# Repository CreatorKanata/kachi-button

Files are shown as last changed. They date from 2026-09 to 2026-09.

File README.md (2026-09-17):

<p align="center">
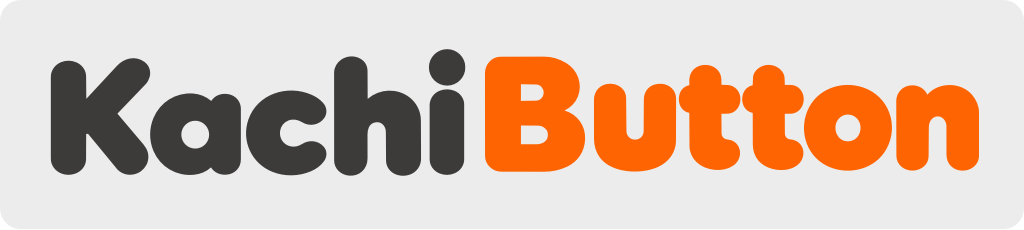
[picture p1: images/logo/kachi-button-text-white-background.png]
Kachi Button
  
</p>

<p align="center"><strong>Click for Fun. Type for Real.</strong></p>

Kachi Button is an open-source, programmable keychain keyboard. Enjoy the click of its mechanical keys, then connect it via USB-C to type your favorite phrases with a single press. “Kachi” is the Japanese sound of a click.

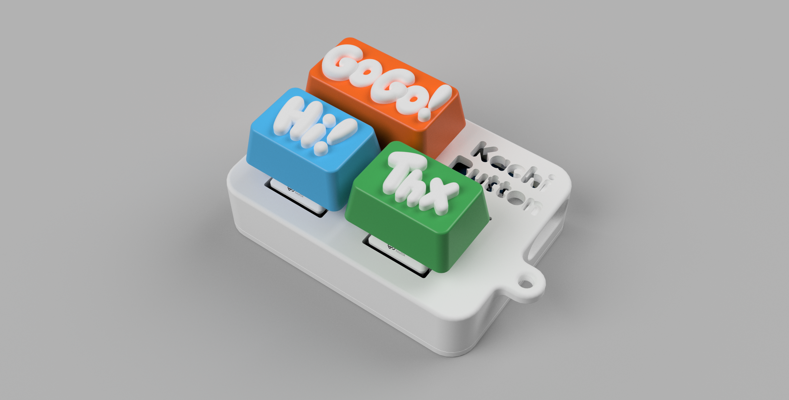
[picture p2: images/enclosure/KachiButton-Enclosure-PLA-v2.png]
Kachi Button with the PLA v2 enclosure


The product concept combines three mechanical keys, a USB-C connection, and a compact enclosure. Use cases include quick game chat messages and recurring prompts such as “OK,” “Continue,” and “Do it.” The image above is a 3D rendering of the PLA v2 enclosure and keycaps.

## Hardware v1

The first PCB uses a WCH CH552E, three MX-compatible switches, a USB-C connector, and a status LED. One large key sits above two smaller keys. The two-layer board has R5 corners and is intended for a snap-fit enclosure. All resistors and capacitors use 0402 packages.

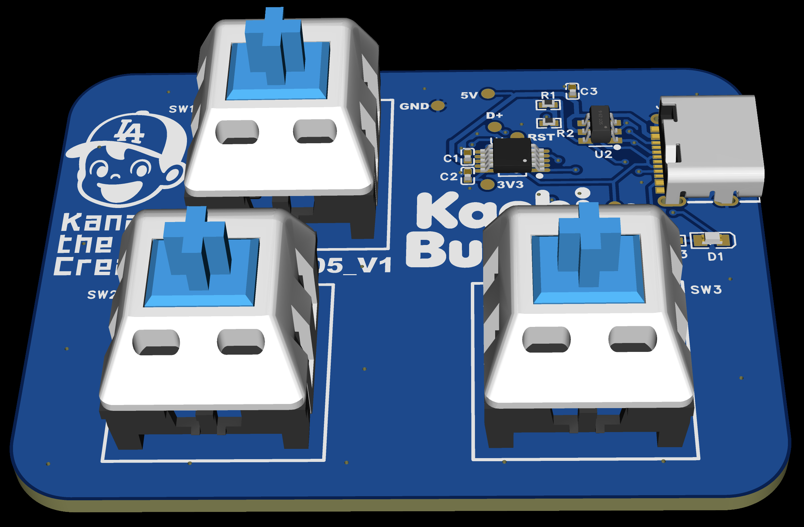
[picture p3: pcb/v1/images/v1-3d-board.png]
Kachi Button v1 PCB 3D rendering


See the [top and bottom board previews](pcb/v1/README.md#board-previews) for routing and silkscreen details.

Manufacturing exports are available in [pcb/v1](pcb/v1/README.md), including Gerber, BOM, pick-and-place, and STEP files. The design record explains the circuit, component choices, layout, and outstanding validation.

The [USB keyboard firmware](firmware/README.md) defaults to `Go Go!`, `Hi!`, and `Thx` on the upper, lower-left, and lower-right keys. A USB command-line tool can edit and save each key’s text, repeat count, and interval in milliseconds; host-initiated firmware upload is supported. See the [bring-up record](firmware/bring-up.md) for build and hardware verification. A browser-based configuration tool remains planned; enclosure fit and broader hardware validation remain separate checks.

## Development

See the [detailed specifications](docs/README.md) for product requirements, PCB dimensions and placement, firmware, and the enclosure to be designed in 3D CAD. The latest design decisions fix keycap sizes at 33 × 18 mm for the upper key and 25 × 18 mm for each lower key; enclosure dimensions remain provisional. The purchased USB-C cable is nominally 10 cm long.

For keyboard software, start with [firmware development](docs/firmware-development.md), the [feature inventory](docs/firmware-features.md), and [firmware internals](docs/firmware-internals.md). These describe the implemented CLI configuration and upload paths; the product specifications also include future requirements.

PCB and schematic work uses the EasyEDA MCP / `easyeda-api` skill workflow. See [PCB development with EasyEDA](docs/pcb-development.md) for connection setup, editing practices, verification, and export steps.

Chat with contributors in Japanese. Write documentation, code, code comments, issues, and pull requests in English, as specified in [AGENTS.md](AGENTS.md).

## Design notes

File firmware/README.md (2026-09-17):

# Kachi Button firmware

Configurable text macros for PCB v1 (CH552E), September 12, 2026.

See the [development guide](../docs/firmware-development.md), [feature inventory](../docs/firmware-features.md), and [internals](../docs/firmware-internals.md) for task-oriented documentation.

| ID | Physical key | GPIO | Default text |
| --- | --- | --- | --- |
| 0 | Top / SW1 | P1.5 | `Go Go!` |
| 1 | Lower left / SW2 | P1.6 | `Hi!` |
| 2 | Lower right / SW3 | P1.7 | `Thx` |

Each key has 0–32 printable ASCII characters, 1–99 repetitions and a
0–60,000 ms repeat interval. Defaults use one repetition and 0 ms.
An empty text disables that key. One physical press executes the entire macro;
holding the key does not retrigger it. No Enter or separator is added.

The interval is the software delay after the final release report of one copy
is queued and before the next copy begins. Each character still has a key-down
and release report, paced by the USB endpoint. Actual host-observed timing is
quantized by the 10 ms USB polling interval and host scheduling; this is not a
precision pulse generator. A zero interval adds no extra delay.

Use a US/ABC-compatible Latin keyboard layout with other modifiers released.
The firmware accounts for Caps Lock, but does not implement IME conversion,
Unicode text, arbitrary keyboard layouts, or automatic Enter.

Inputs have pull-ups and 15 ms debounce. Held startup/resume keys require release.
Only one macro runs at a time; presses while busy are discarded until release.
Simultaneous presses use Top, Left, Right priority. Settings updates do not alter
an already running macro; each accepted press snapshots its text/count/interval.
USB reset or suspend cancels the current macro and staged configuration edit.

## Configure from the host

Python 3 and a libusb shared library are required (on macOS, 1.0.30 or newer). The [server-free browser settings page](../configure-html/README.md) uses Chrome WebUSB instead
of these Python tools. No CDC serial port is included. These commands use vendor requests on the keyboard's
USB control endpoint without claiming/detaching its HID interface.

```sh
# Read all keys and save status.
python3 firmware/configure.py get

# A single top-key press types Go! three times with 250 ms gaps; persist it.
python3 firmware/configure.py set 0 --text 'Go!' --repeat 3 --interval-ms 250 --save

# Changes without --save apply in RAM; persist all three keys explicitly.
python3 firmware/configure.py save
```

For a library outside the search path, place
`--libusb /path/to/libusb-1.0.dylib` before the subcommand, or set the
`KACHI_LIBUSB` environment variable. macOS libusb 1.0.29 was observed deadlocking
in exit during USB detach; the tool rejects it before opening USB. Version
1.0.30 contains [Darwin concurrency fixes](https://github.com/libusb/libusb/blob/master/ChangeLog). Set operates on one key;
`--repeat` defaults to 1 and `--interval-ms` to 0. Run one configuration writer
at a time. The tool checks capability, validates input, applies a complete key
atomically, reads it back, and waits for verified save completion when requested.

## Saved settings

CH552 provides 128 logical DataFlash bytes. This version uses bytes 0–113:
`KC`, schema 1, three 36-byte macros, CRC-16/CCITT-FALSE (little endian), and
commit marker `0xa5`. Each macro is count, length, interval-ms low/high bytes,
then 32 zero-padded ASCII bytes. Addresses 114–127 remain unused.

Save invalidates the marker first, updates and reads back every changed byte,
then writes the commit marker last. Identical saves perform no EEPROM writes.
Invalid schema, checksum, text, ranges, or commit marker loads all defaults.
Only explicit save writes EEPROM. Flashing application code leaves it intact.

There is one record, not two: interrupted save can lose the previous saved
configuration and fall back to defaults. The implementation never intentionally
loads a partially committed record. Unchanged valid records remain available if
failure occurs before invalidation. A save error is returned to the host.

The pinned [CH55xduino EEPROM implementation](https://github.com/DeqingSun/ch55xduino/blob/ch55xduino/ch55xduino/ch55x/cores/ch55xduino/eeprom.c)
uses logical byte addresses 0–127 and the CH552 DataFlash write sequence.
The wrapper masks interrupts for each byte's protected register accesses; saving
runs in the foreground, with status requests available between byte operations.

## Firmware upload and waiting

From the repository root, use these short commands:

```sh
make flash-first  # First flash or recovery: already connected in native WCH ISP.
make flash        # Later updates: connected as a running Kachi Button.
```

Both commands flash the existing `firmware/build/compiled/kachi_button.ino.hex`
with verification enabled; neither rebuilds it. Build first if the HEX is absent
or you have changed firmware source. Override the image with
`make flash FIRMWARE=/absolute/path/to/file.hex` (also supported by `flash-first`).
A first-flash command does not put a running keyboard into ISP; use `make flash`
for that. If an update reports `found 0 / 1`, the device is already in ISP:
use `make flash-first`. Connect only the intended target.

For tools outside PATH, copy `firmware/local.mk.example` to `firmware/local.mk`
and set `PYTHON`, `WCHISP`, and optionally `LIBUSB` to their installed paths.
The local file is ignored by Git. Values are plain paths, without shell quotes;
spaces in paths are supported. macOS requires libusb 1.0.30+ matching Python's
architecture. `make` shows help; `make -n flash` previews the command without USB
access. Existing long-form commands remain available below.

Protocol v2 accepts a host ISP-entry command from normal mode or write-wait mode.
An AI/host tool can now update firmware without a physical key gesture:

```sh
python3 firmware/flash.py --status
python3 firmware/flash.py firmware/build/compiled/kachi_button.ino.hex --wchisp /path/to/wchisp

# Optional: enter native ISP without immediately flashing.
python3 firmware/flash.py --enter
```

The uploader validates the known firmware protocol, requests ISP, waits for the
new USB identity, and invokes wchisp with verification enabled. It refuses
unknown protocols, missing files/tools, multiple keyboard targets, or an already
attached WCH ISP target. Keep only the intended target attached during upload.
These local USB commands are intentionally host-controlled, not authenticated.

The physical alternative remains: hold all three keys before connecting USB,
then keep holding for 2 seconds. Slow blinking (250 ms on/off) changes to fast
blinking (75 ms on/off). After confirmation, release the keys and wait indefinitely.
USB reset/suspend and key changes do not clear confirmed waiting; power/MCU reset
does. Text output is suppressed in this state. Reconnect without keys for normal
operation. Entering active normal HID mode lights the LED for 2 seconds, then
leaves it off. Each debounced physical press then produces one 30 ms on pulse
and returns to off. The entry indication takes priority during its 2 seconds;
presses still type normally but do not interrupt or extend that indication.
Reconfiguration or resume starts a new entry indication.
This includes presses ignored during a running macro; holding a key does not
repeat the pulse. Software-generated repetitions do not trigger extra pulses.
The nonblocking pulse timer yields to startup/write-wait patterns and USB suspend.

The application retains identity `1209:c55d` while waiting. Native ISP starts
only when the host requests it, then the application LED loop stops. Native ISP
has its own timeout; use the integrated uploader when programming. A successful
flash resets the device into the new application. Fast blinking is guaranteed by
the application waiting logic, not during native ISP itself.

Bootloader entry follows pinned CH55xduino 0.0.26 `USBCDC.c`: USB detach, disable
interrupts/timer mode, 100 ms delay, call CH552 address `0x3800`. No configuration
registers or bootloader code are rewritten. Boards still running protocol-v1 firmware
require the three-key wait for the one-time upgrade; this uploader also
supports that legacy wait state. The oldest K/N/A firmware requires hardware ISP.

### Native ISP and recovery

A blank CH552 normally appears as WCH ISP `4348:55e0`. Use tested
[wchisp](https://github.com/ch32-rs/wchisp) 0.3.0, commit
`cefd8707df345f1fbd7795e15367281f440bbf05`:

```sh
wchisp info --chip CH552
wchisp flash firmware/build/compiled/kachi_button.ino.hex
```

The command erases application flash, programs, verifies, and resets. If an
upload fails after erasing the application, use native ISP directly for recovery.
The retained factory hardware-entry setting uses D+. With USB disconnected,
connect D+ to 5 V through a 10 kOhm resistor, then reconnect USB; remove the
pull-up after ISP entry. Never directly short D+ to 5 V. PCB v1 has labeled test
pads. This hardware recovery wiring has not been physically tested on this board.
See [upstream entry instructions](https://github.com/DeqingSun/ch55xduino#installation).

## Build and test

Dependencies: Python 3, a native C compiler, Arduino CLI and CH55xduino 0.0.26
(SDCC build.13407_4, MCS51Tools 2026.07.10); tested CLI version is 1.3.1.

```sh
export ARDUINO_DIRECTORIES_DATA="$PWD/.arduino-data"
arduino-cli core update-index --additional-urls https://raw.githubusercontent.com/DeqingSun/ch55xduino/ch55xduino/package_ch55xduino_mcs51_index.json
arduino-cli core install CH55xDuino:mcs51@0.0.26 --additional-urls https://raw.githubusercontent.com/DeqingSun/ch55xduino/ch55xduino/package_ch55xduino_mcs51_index.json
python3 firmware/build.py --data "$ARDUINO_DIRECTORIES_DATA"
```

Use `--cli /path/to/arduino-cli`, `--out /path/to/build`, or `--test-only` as
needed. All limits, timing and identifiers are centralized in `config.py`.
Output is `firmware/build/compiled/kachi_button.ino.hex` with map/memory files.

Build staging copies pinned upstream HID descriptors/control handlers and makes
checked substitutions for product strings, power, lifecycle hooks and vendor
requests. Application flash is limited to 14,336 bytes; 148 XRAM bytes are
reserved for USB, leaving 876 for the application. CH55xduino's USB code and the
ASCII map are LGPL-2.1; retain the corresponding source, license and relinkable
objects when redistributing binaries.

USB identity is the upstream development VID:PID `1209:c55d`, not an allocated
production identifier. One boot keyboard interface uses endpoint `0x81` with
eight-byte reports at 10 ms. Remote wake is not advertised. Suspend extinguishes
the normal LED; confirmed write-wait continues blinking. Power consumption and
suspend compliance have not been measured.

## USB control protocol v2

All requests use wValue `0x4b42`. IN type is `0xc0`; OUT type is `0x40`.
OUT commands have zero data length; mutation occurs only after status-stage ACK.
A new SETUP cancels an unacknowledged command. Invalid requests stall.

| Request | Direction/length | wIndex | Meaning |
| --- | --- | --- | --- |
| `0x5a` | IN / 4 | 0 | `KB`, version 2, waiting flag |
| `0x5b` | OUT / 0 | 0 | Enter native ISP from either mode |
| `0x60` | IN / 8 | 0 | `KC`, version 2, max text, max count, result, saving, dirty |
| `0x61` | IN / 1–8 | offset high, key ID low | Read a macro slice, within 36 bytes |
| `0x62` | OUT / 0 | key ID | Begin a new single-key staged edit |
| `0x63` | OUT / 0 | byte value high, offset low | Append next sequential byte, 0–35 |
| `0x64` | OUT / 0 | 0 | Validate and atomically apply the complete staged macro |
| `0x65` | OUT / 0 | 0 | Queue save, poll info for completion |
| `0x66` | IN / 8 | 0 | Factory ID: `KI`, format 1, five ID bytes, most significant first |

Save result: 0 success, 1 pending, 2 storage error. Edits and ISP entry stall
while saving; read-only requests remain available. Repeating an edit must start
with begin; a second client can replace a staged edit, so writers must serialize.
No configuration command emits keyboard input.

## Validation

Eight native C suites cover scanning, default reports, repetitions and ms gaps,
snapshot behavior, startup waiting, remote ISP validation, the actual EP0 adapter,
settings bounds, EEPROM round-trip, corruption and all injected partial writes.
Six Python tests cover uploader gating/ordering and configuration encoding/wire
commands. Native tests do not prove physical timing, EEPROM or signal quality.
See [bring-up.md](bring-up.md) for build sizes and actual hardware checks.

Dismiss macOS Keyboard Setup Assistant with Quit; three keys cannot complete its
full-keyboard identification procedure.

## Save-completion LED

Firmware with the September 13, 2026 save-feedback change lights the LED for
1 second after a successful, verified settings save in normal HID mode. This
also applies to an unchanged save and saves from the Python tool. Temporary
apply and failed saves do not trigger it. This device-side change requires a
firmware update; changing the HTML alone cannot enable it on older firmware.

Save feedback takes priority over HID-entry and key-press indications; typing
continues and presses do not extend the 1-second duration. Another successful
save restarts it. Startup/write-wait blinking, USB suspend/reset, and ISP entry
retain priority and can cancel the indication. Native tests verify timer bounds,
wrap, failure, retrigger, and priority; physical LED timing is not measured.

The optional `0x66` request reads the factory 40-bit CH552 ID without ISP entry
or flash writes. It is available in normal and write-wait modes and during save.
Older protocol-v2 firmware stalls it; callers may show ID unavailable while
continuing settings operations. The USB serial-number descriptor remains absent.
See the [browser ID guide](../configure-html/README.md#factory-chip-id) for memory
addresses and the datasheet reference.

## USB manufacturer

New firmware advertises `HAPT Lab, LLC` as its USB manufacturer. The product
remains `Kachi Button`. Host tools and the browser accept both this name and
legacy `CreatorKanata` devices so existing firmware can still be upgraded.
Product/VID/PID and protocol checks remain in place; other manufacturers are
not accepted. Historical bring-up records retain the names observed at the time.

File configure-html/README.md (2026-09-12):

# Browser keyboard settings

A static HTML/CSS/JavaScript settings page for Kachi Button protocol v2.
No server, Python process, libusb installation, npm packages, or network requests
are needed to use the page. Open `index.html` in desktop Chrome, keeping the
adjacent JavaScript and CSS files in the same folder.
The project-root `configure-html/` directory can be copied on its own for use;
only regenerating protocol constants requires the sibling `firmware/` sources.

## Use

1. Connect the intended Kachi Button with USB.
2. Open `index.html` in Chrome and click **Connect USB**.
3. Select Kachi Button in Chrome's USB permission picker.
4. Edit Go Go! (top, ID 0), Hi! (lower left, ID 1), and Thx (lower right, ID 2).
5. Choose **Apply & save to device** for persistent settings, or **Apply temporarily**
   for RAM-only changes. Success is shown only after device read-back verification.
6. Click **Try your buttons**, select a US/ABC input source, and press a physical key.

Key names match the printed keycaps and remain fixed when the assigned text changes.
Each key heading uses three lines: small switch position, keycap name, then small ID.
This order is retained on narrow screens.

Text supports 0–32 printable ASCII characters; empty text disables a key.
Repetitions are 1–99, and the gap between full copies is 0–60,000 ms.
No Enter or separator is added. A count of 1 sends the text once. The interval
is not a per-character delay or a guaranteed start-to-start period.

The form does not write on each keystroke. Re-reading asks before discarding
unsubmitted edits. Disconnects and errors keep form values but require a fresh
connection before further writes. A failed multi-key operation may have applied
earlier keys; read the device before retrying. Updates are atomic per key, not
across all three keys. Save persists all keys, with the firmware's existing
single-record power-loss limitations. Run only one settings writer at a time,
including other browser tabs and Python tools.

## Browser transport

The page uses `navigator.usb.requestDevice`, checks the USB identity and protocol,
and sends vendor, device-recipient control transfers on endpoint zero. It does
not claim the HID interface, reset the device, use WebHID keyboard reports, or
change firmware. Chrome requires user permission for USB selection. Browser/OS
USB access restrictions still apply; this page does not disable them.

The [WebUSB control-transfer specification](https://wicg.github.io/webusb/#usbcontroltransferparameters)
distinguishes vendor device requests from protected HID interface requests.
See also [Chrome's WebUSB documentation](https://developer.chrome.com/docs/capabilities/usb).
File-origin USB availability depends on the browser's policy. If WebUSB is absent
or permission is denied, the page shows an error; it does not start a server or
silently substitute a native bridge. Safari/Firefox support is not assumed.

## Development and validation

Protocol constants are generated from `firmware/config.py`:

```sh
python3 configure-html/generate_config.py
node --test configure-html/tests/protocol.test.cjs
```

Seven Node tests cover encoding and bounds, device identity/read protocol, exact
staged commands, temporary changes, skipped unchanged keys, stalls, bad responses,
and save failures. Node is only required for these development tests.

On September 12, 2026, these tests passed. Chrome rendered the earlier local-bridge
prototype, but the browser automation policy rejected its connect-button action.
The final server-free page's Chrome USB read/edit/save checks remain pending;
simulator tests do not demonstrate actual browser/device compatibility. No device
settings were changed by the browser test and no firmware was flashed.

## Save-completion LED

Firmware with the September 13, 2026 save-feedback change lights the LED for
1 second after a successful, verified settings save in normal HID mode. This
also applies to an unchanged save and saves from the Python tool. Temporary
apply and failed saves do not trigger it. This device-side change requires a
firmware update; changing the HTML alone cannot enable it on older firmware.

Save feedback takes priority over HID-entry and key-press indications; typing
continues and presses do not extend the 1-second duration. Another successful
save restarts it. Startup/write-wait blinking, USB suspend/reset, and ISP entry
retain priority and can cancel the indication. Native tests verify timer bounds,
wrap, failure, retrigger, and priority; physical LED timing is not measured.

## Factory chip ID

Connect USB and Read device show **Chip ID**, the CH552 factory 40-bit ID,
formatted as five uppercase hexadecimal bytes, most significant first. It is
fixed by the chip and independent of key names, assigned text, and saved settings.
The browser reads it directly with a read-only USB request; it does not enter ISP.
Older firmware returns an unsupported-request stall and shows an update notice,
while the existing settings controls remain available. Transport errors and
malformed replies are not treated as a valid ID; disconnect clears the display.

The implementation follows the [WCH CH552 datasheet, section 6.7](https://cdn-learn.adafruit.com/assets/assets/000/129/847/original/CH552DS1.PDF?1715004485=).
It reads code addresses 0x3FFA, 0x3FFF, 0x3FFE, 0x3FFD, 0x3FFC, skipping the
reserved 0x3FFB. This is different from the shared chip-model register 0x52 or
USB VID/PID. Some ISP tools show only the lower four bytes in another order.
Eight browser protocol tests now include ID formatting, legacy stalls, malformed
responses, and disconnection. Native EP0 tests verify the byte order and request
validation while saving is active.

The September 13 JST firmware was flashed and verified. Host USB reads returned
`79-BE-CA-A2-BE` twice on the connected board and confirmed saved settings were
retained. The browser uses the same request; actual browser display is unverified.

## USB manufacturer

New firmware advertises `HAPT Lab, LLC` as its USB manufacturer. The product
remains `Kachi Button`. Host tools and the browser accept both this name and
legacy `CreatorKanata` devices so existing firmware can still be upgraded.
Product/VID/PID and protocol checks remain in place; other manufacturers are
not accepted. Historical bring-up records retain the names observed at the time.

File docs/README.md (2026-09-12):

# Kachi Button Development and Specifications

Updated September 12, 2026. These English specifications consolidate the preliminary concepts, the design discussion, PCB v1 exports, and the latest product reference.

| Document | Scope |
| --- | --- |
| [Product](spec/product-spec.md) | Purpose, experience, scope, purchased cable, and delivery milestones |
| [PCB](spec/pcb-spec.md) | Electrical interfaces, dimensions, placement coordinates, manufacturing, and checks |
| [Firmware and configuration](spec/firmware-spec.md) | Key behavior, USB HID, WebHID, storage, and acceptance criteria |
| [Enclosure](spec/enclosure-spec.md) | Parametric 3D CAD, confirmed keycap sizes, board retention, and cable storage |
| [Keyboard development](firmware-development.md) | Build, configure, enter upload mode, flash, validate, and troubleshoot |
| [Keyboard features](firmware-features.md) | Implemented behavior, LED patterns, limits, and verification status |
| [Keyboard internals](firmware-internals.md) | Source map, USB transactions, storage format, and change boundaries |
| [PCB development](pcb-development.md) | EasyEDA MCP / `easyeda-api` skill workflow |
| [PCB v1 release](../pcb/v1/README.md) | Version-specific design history, previews, and manufacturing files |

Specifications live in `docs/spec/`; development workflows remain directly under `docs/`.

## Authority and status

**Confirmed** means explicitly decided by the user. **Exported** means represented in the supplied v1 design files. **Required** means behavior or a deliverable to implement; it does not mean implemented. **Proposed** identifies an engineering choice that still needs implementation review. **TBD** means information or a decision is missing.

Use the latest user decisions for product requirements and the actual versioned exports for existing PCB geometry. If these conflict, record the incompatibility and resolve it explicitly; do not silently rescale the PCB or keycaps. Product images guide appearance but do not establish unspecified dimensions or prove physical fit.

The ignored `docs/concept/` directory contains the original planning input. These specifications are self-contained and do not require those local files to be present.

## Current decisions

| Topic | Current baseline |
| --- | --- |
| Key arrangement | One upper wide key, two lower keys |
| Keycap size | Confirmed: upper 33 × 18 mm; lower two each 25 × 18 mm |
| Product reference | `images/kachi-button-product2.png` is the latest appearance reference |
| Enclosure size | 62 × 36 × 18 mm in the image is provisional, not a manufacturing requirement |
| PCB | Existing v1, approximately 55 × 41 mm, four R5 corners, two copper layers |
| Assembly | Components on Top; resistors and capacitors all 0402 |
| Retention | Snap-fit PCB retention; no corner screw holes |
| Power | USB-C 5 V sink, without USB PD negotiation |
| Cable | Purchased: nominal 10 cm, USB-C male to USB-C male, white |
| Configuration | Implemented: USB CLI text/count/ms-interval editing and DataFlash save; browser/vendor HID remains planned |
| Development language | Japanese chat; English documentation, code, comments, issues, and PRs |

Earlier 0603 passive suggestions, a horizontal three-key row, a 65 × 25–30 mm board, and a 15–20 cm cable are superseded. Earlier “2U / 1U” shorthand must not replace the confirmed millimeter dimensions. The v1 design record remains a historical account of PCB work.

## Open decisions and dependencies

| Item | Required resolution |
| --- | --- |
| Enclosure dimensions | CAD must contain the existing board and measured component stack; the pictured 36 mm case dimension is smaller than the board's approximately 41 mm dimension |
| Keycap fit | Verify MX stem geometry, offset from the cap center, height, travel, and underside clearances with actual parts |
| Cable | Confirm USB data support; measure length convention, overmolds, strain relief, and usable bend radius |
| Firmware | CH55xduino 0.0.26 selected; host-only upload and persistence verified; measure physical repeat timing, LED waveform, and power behavior |
| USB identification | Establish appropriate VID/PID values before release; do not assume example identifiers are assigned |
| Assembly | Recheck stock/pricing and verify switch and USB-C assembly handling |
| Prototype | Initial USB/HID bring-up and fixed-text input verified; enclosure fit and broader electrical validation remain pending |

The delivered PCB, firmware, and enclosure should be versioned independently and identify their compatible counterparts. Do not treat a PCB manufacturing export as a completed product release.

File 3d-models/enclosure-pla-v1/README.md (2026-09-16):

# Kachi Button PLA Enclosure Prototype

Created September 6, 2026 from the user's current Fusion `asm` placement. This is a printable prototype, not a physically validated enclosure release.

## Current STL exports (September 16, 2026)

The current printable enclosure is provided as separate files:

- [Top STL](KachiButton-Enclosure-PLA-v1-Top.stl)
- [Bottom STL](KachiButton-Enclosure-PLA-v1-Bottom.stl)

These replace the combined `KachiButton-Enclosure-PLA-v1.3mf` export. The original September 6 descriptions and subsequent design notes below are historical snapshots; use the current STL geometry for this revision.

The STL files retain the assembly orientation: Y is the height axis. Their bounding dimensions in file X/Y/Z are 71.2921 × 12.6 × 47.2 mm for Top, including the keyring ear, and 63.3 × 6.7 × 47.2 mm for Bottom. STL does not encode units; import as millimeters and choose the print orientation in the slicer.

Both binary STL files passed triangle-record, finite-coordinate, nondegenerate-triangle, and closed-edge checks. These checks establish mesh integrity, not physical fit or strength.

## Initial editable source and exports

The Fusion file is `KachiButton-Enclosure-PLA-v1`, saved in HAPT Lab / `kachi-button` (file ID `urn:adsk.wipprod:dm.lineage:ralD4T5OSdiXAXDjQ-ULcw`). It contains the reference assembly plus separate `Enclosure Top` and `Enclosure Bottom` components. Named sketches, extrusions, lofts, and fillets remain editable in the timeline; the outline sketches are not fully dimension-constrained.

- `KachiButton-Enclosure-Top.step`: the box-shaped top and twelve separate logo solids.
- `KachiButton-Enclosure-Bottom.step`: the bottom plate, supports, and integral latches as one solid.
- `KachiButton-Enclosure-Top.3mf`: thirteen mesh objects with their relative placement preserved.
- `KachiButton-Enclosure-Bottom.3mf`: one mesh object.

Exports use millimeters and component-local coordinates, not an automatically arranged print plate. Keep all Top objects together when importing into a slicer.

## Geometry

| Feature | Prototype value |
| --- | --- |
| Footprint | 63.3 × 47.2 mm |
| Case height | 23.25 mm, excluding protruding keycaps |
| Overall height with current keys | 30.25 mm |
| Outer plan corners | R6 mm |
| Top outer edge | R2.5 mm |
| Bottom outer edge | R0.4 mm |
| Nominal side walls / roof / floor | 1.5 ordinary / 2.4 / 2.0 mm; local snap receivers and USB regions remain reinforced |
| PCB side clearance | Approximately 0.3 mm along the ordinary straight walls |
| Top surface | 3 mm above the keycap lower edges |
| Right outer face | Approximately 6 mm beyond the PCB right edge |
| Bottom-to-Top seam clearance | 0.25 mm |
| PCB upper-stop clearance | 0.25 mm above the nominal PCB top |
| Key opening clearance | 0.5 mm at the outer full-skirt edges, recentered on the current key placements |

In component coordinates, X is board width, Y is board depth, and Z is height. The PCB bottom is Z=0 and its top is Z=1.6 mm. The keycap bottoms are Z=13.55 mm, the enclosure top is Z=16.55 mm, and the bottom outside is Z=-6.7 mm. This maps to the reference assembly as `(X, Z, -Y)`.

The key openings form one stepped opening. Thin inter-key bridges and small junction protrusions are removed; the inward step has an R1.4 blend.

## Screwless assembly

Top is the box with internal catch pockets. Bottom has two broad front latch wedges and two thick fixed rear tabs, all below the PCB. This replaces the earlier four fine hooks.

| Retention feature | Current geometry |
| --- | --- |
| Front wedge contact width | 4 mm |
| Front wedge solid shoulder height | 2.0 mm |
| Front entry ramp height | 0.55 mm |
| Front lateral spring | 10 mm free length, 2 mm wide in the bending direction, 2 mm high |
| Spring relief slots / root fillets | 0.6 mm / R0.4 |
| Front lateral engagement | 0.55 mm nominal |
| Rear fixed tabs | 8 mm wide, 2 mm thick; 2 mm-deep roots |
| Pocket lower lips | 1.5 mm front / 1.7 mm rear |

Bottom now has five PCB supports. The right upper support is a 4 × 5 mm pad directly beneath J1, centered at board X=51.5, Y=31 mm, to support connector insertion loads. Its top is at the PCB underside. The other three supports retain their established locations. Top uses five 3 mm-wide ribs that extend continuously from the side walls to their contact ends, stopping 0.25 mm above the nominal PCB top. They have no hooks above the board.

Assemble with the keycaps removed: place the PCB on Bottom, engage the rear fixed tabs in Top at a slight angle, then close the front latches. Install the keycaps after closure. Release the front latches through the Bottom relief slots before withdrawing the rear tabs. The complete angled assembly/release path still needs physical testing; do not force it if the USB receptacle or PCB catches.

The new wedge removes the former 0.5 mm-thick isolated shoulder. With Bottom flat on the bed, the spring bends in the layer plane, but the upright wedge still transmits force across layers. Larger geometry reduces reliance on fine printed details; it does not establish PLA strength or cycle life. Print a local latch/pocket trial before the full enclosure.

## USB and cable parking

The right wall has an enclosed, rounded live USB tunnel rather than a large rectangular window. It runs toward J1 and screens the surrounding PCB. The preliminary opening is 9.4 × 3.6 mm with R1.6 corners, centered at board depth 31 mm and height 3.15 mm.

The blind parking socket is to its left when looking directly at the right face, at the same height. Its preliminary opening is 9.2 × 3.6 mm with R1.6 corners, centered at board depth 14 mm. Its depth from the right outer face is 3.75 mm, leaving a 2 mm blind end wall. It is entirely mechanical and has no electrical contacts.

**Cable fit is unresolved.** The purchased 10 cm cable's exposed metal length and white overmold dimensions have not been supplied. The live receptacle is about 6 mm behind the exterior face: a short metal plug may require the socket mouth to be recessed so its overmold can approach J1. Do not assume full insertion or parking retention from these nominal openings. Measure the cable and print a socket fit coupon before printing the complete case.

## Logo and colors

The Top uses `images/logo/kachi-button-text-2lines.svg`, at approximately 22 mm wide in the upper-right area. Twelve disconnected glyph solids fill matching 0.4 mm-deep pockets, flush with the top surface.

- Enclosure shells: white.
- `Logo Kachi ...` bodies: SVG gray `#3C3B3A`.
- `Logo Button ...` bodies: SVG orange `#FE6401`.

Assign the corresponding PLA filaments by object name in the slicer. Do not move or independently auto-arrange the logo objects.

## PLA printing and verification

Suggested initial setup: 0.4 mm nozzle, 0.2 mm layers, and four perimeters where geometry allows. Inspect the 2 mm spring strips for continuous extrusion paths; actual line placement depends on the slicer. Tune temperatures and cooling to the selected PLA rather than using an unverified universal profile.

Orient Bottom with its flat outside on the bed. Orient Top with its outside top face toward the bed, keeping the inlays registered; the rounded perimeter may need localized support or a brim. Inspect bridges and supports inside both USB sockets and around latch ramps. Keep support contact off the small latch shoulders where possible. These are starting instructions, not a validated slicing profile.

CAD checks found no enclosure-to-PCB interference and no key-to-Top interference at 0, 2, and 4 mm downward key offsets. The 4 mm offset is a clearance check, not a measured switch travel specification. The imported PCB model contains its own internal overlaps; these were separated from enclosure interference. Top and Bottom have no overlapping volume in their assembled positions.

All enclosure features were healthy at export. The shell/plate are solids, all twelve logo inlays are 0.4 mm thick, and all fourteen exported mesh objects passed closed-edge checks. Physical PLA strength, repeated latch cycles, key operation, cable insertion, and parking retention remain untested.

## Assembly placement update

On September 6, 2026, keycap alignment was corrected against `asm` version 5. The first synchronization copied occurrence transforms but left the previous rigid joints unchanged; recomputation restored those joint-driven positions. That earlier transform-only verification was insufficient.

The enclosure's three existing rigid joints now have X and Y offsets of -0.1403226 mm in their own joint coordinate systems. These values differ from the source assembly's offsets because the source uses different joint reference geometry. After recomputation, saving, and switching documents, all three occurrence transforms and every keycap body's bounding box and volume match the source assembly within the CAD check tolerance (0.000001 mm for positions). Top clearance checks also pass at 0, 2, and 4 mm downward offsets, and all joints remain healthy.

This correction changes assembly constraints and reference key placements only. Top and Bottom solids and their standalone exports remain applicable. Physical key operation remains untested.

## Key opening clearance correction

After the joint alignment correction, the Top opening and its two junction cleanup sketches were translated by +0.215198 mm in board X and +0.215222 mm in board Y. The keycap placements remain unchanged. The measured straight outer footprint gaps are 0.499957–0.500000 mm; the shared inter-key opening and its rounded junction remain continuous. CAD interference checks passed at 0, 2, and 4 mm downward key offsets, and key positions remained stable after recomputation. Top features are healthy and the thirteen exported meshes have closed edges. The Top STEP and 3MF exports were regenerated for this opening correction. Physical printed clearance remains untested.

## Additional rear-right corner support

A paired support was added near the user-marked rear-right corner. Bottom has a 3 × 2 mm pad at board X48–51, Y38–40 mm, extending from the inside floor Z=-4.7 mm to the PCB underside Z=0. Top has a matching 3 mm-wide rib extending to the rear wall at Y41.6 mm; its contact face is at Z=1.85 mm, preserving the nominal 0.25 mm clearance above the PCB. Both features join their respective shells. The Bottom contact footprint was checked inside the imported PCB outline. CAD checks found no enclosure-to-electronics or Top-to-Bottom overlap and no key interference at 0, 2, and 4 mm downward offsets. Both exports were regenerated and passed closed-mesh checks. Actual solder clearance and printed retention still require prototype validation.

## FDM structural reinforcement and shorter springs

The user identified fragile rear tab roots and specified at least 1.5 mm structural sections, preferably 2 mm. The rear tab roots were widened from 0.7 to 2 mm and the tabs thickened to 2 mm. Front spring sections and latch shoulders are also 2 mm. The final spring free length is **10 mm**, per the user; the 0.6 mm end relief is separate from that length. Receiver pocket lower lips are 1.5 mm front and 1.7 mm rear, with approximately 2 mm outer backing. Left, front, and rear exterior walls were expanded, increasing the footprint by 0.4 mm in width and 2.2 mm in depth while retaining height and key placement. The three original narrow Bottom posts were widened from 1.6 to 2 mm.

The right-side Top PCB stops were retracted 0.7 mm toward the wall (contact ends now at board X54 mm), retaining their 3 mm width. USB tunnel surrounding walls and the parking socket ceiling/end wall are now 2 mm. The parking socket is consequently 1 mm shallower. The roof is 2.4 mm, leaving 2 mm beneath the 0.4 mm logo inlays.

CAD checks passed for enclosure-to-PCB, Top-to-Bottom, and key clearance at 0/2/4 mm downward offsets. Features are healthy and both exported parts pass closed-mesh checks. These checks establish geometry, not PLA flexural strength: the 10 mm × 2 mm spring will be stiffer than the previous long thin spring, and assembly force and repeated use must be evaluated on a printed latch/pocket sample. Do not equate interference-free CAD with a tested snap fit.

## Bottom PCB post thickness update

All five Bottom PCB supports now have a minimum nominal cross-section dimension of 2.4 mm or more along their full 4.7 mm rise from the floor. The three original posts are 2.4 × 3 mm, the rear-right post is 3 × 2.4 mm (X48–51, Y37.8–40.2 mm), and the USB support remains 4 × 5 mm. This supersedes the earlier 2 mm post dimensions; the latch geometry remains as specified separately. Feature and section-dimension checks passed, together with enclosure/PCB interference checks and key clearance at 0/2/4 mm. The Bottom STEP and 3MF were regenerated and the mesh is closed.

## Ordinary wall thickness update

Per the user, ordinary side walls are now 1.5 mm while the Bottom plate remains 2 mm. The Top cavity was expanded to a concentric R4.5 inner outline inside the R6 exterior. Four local reinforcement pads preserve the front and rear snap receivers and their previously specified pocket lips/backing. PCB stop roots were extended to remain joined to the enlarged cavity walls, without moving their contact ends. USB regions, the 2.4 mm roof, and Bottom support posts retain their reinforced dimensions. The exterior footprint is unchanged. Solid-boundary tests checked all four ordinary wall thicknesses; enclosure/PCB and key checks at 0/2/4 mm passed. The Top STEP and 3MF were regenerated and the mesh passed closed-edge checks.

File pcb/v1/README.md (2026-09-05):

# Kachi Button PCB v1

Design record: September 5, 2026.

This directory contains the first hardware manufacturing export set. The product image and the user's final mechanical placement took priority over the preliminary AI-generated concept specification. In particular, v1 uses one upper large key and two lower small keys, rather than three keys in a horizontal row.

## Board previews

### 3D assembly

Kachi Button v1 PCB 3D rendering

The 3D rendering shows the switches and electronics without keycaps or an enclosure.

### Top and bottom

| Top | Bottom |
| --- | --- |
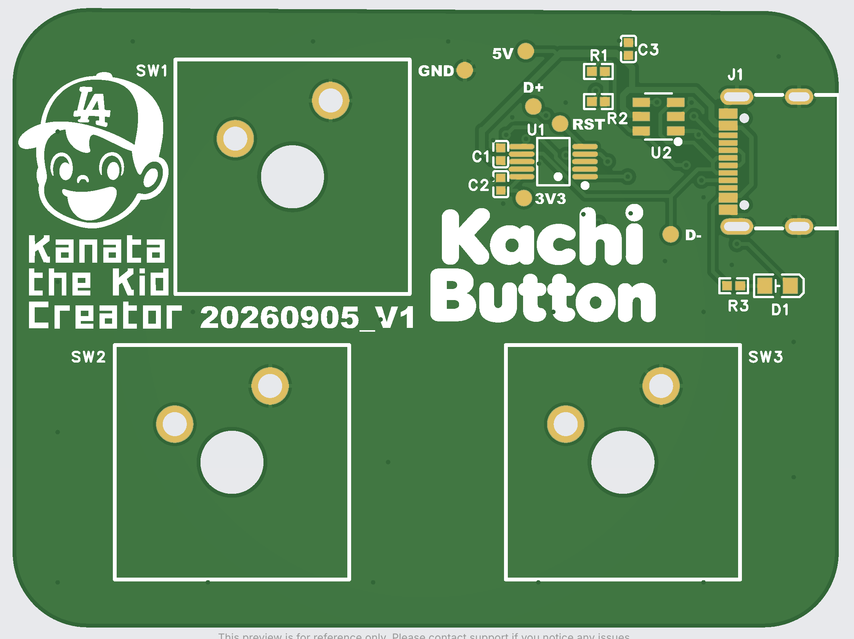
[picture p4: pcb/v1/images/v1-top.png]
Kachi Button v1 top board preview
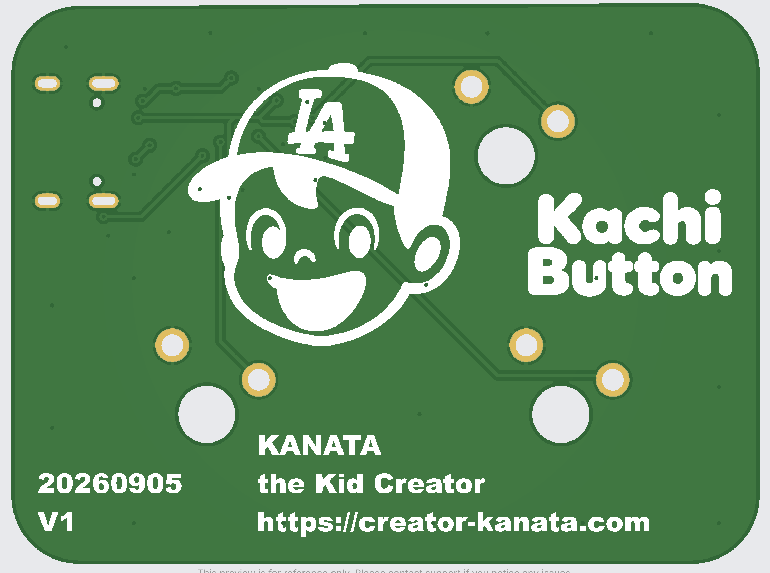
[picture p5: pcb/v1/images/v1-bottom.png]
Kachi Button v1 bottom board preview
|  |  |

These previews show component footprints, routing, test-pad labels, and silkscreen artwork. Click an image to inspect it at full size. Preview colors differ between views; fabrication settings determine the manufactured solder-mask color.

## Release files

Manufacturing and assembly files are grouped in `gerber/`, the STEP model in `board-3d-data/`, and board previews in `images/`.

| File | Purpose |
| --- | --- |
| [Gerber_PCB1_2026-09-05.zip](gerber/Gerber_PCB1_2026-09-05.zip) | Copper, silkscreen, solder mask, top paste, board outline, and drill data |
| [BOM_Board1_Schematic1_2026-09-05.xlsx](gerber/BOM_Board1_Schematic1_2026-09-05.xlsx) | Nine part types, thirteen components, with LCSC part numbers |
| [PickAndPlace_PCB1_2026-09-05.xlsx](gerber/PickAndPlace_PCB1_2026-09-05.xlsx) | Thirteen component positions in millimeters, rotations, and mounting-side information |
| [3D_PCB1_2026-09-05.step](board-3d-data/3D_PCB1_2026-09-05.step) | STEP assembly for mechanical review |

The Gerber and placement exports are timestamped 19:38 on September 5; the STEP header is timestamped 21:15. These are the files supplied for this release. Their common origin in an identical saved EasyEDA revision has not been independently established. Native editable EasyEDA project files are not included in this directory.

## Circuit design

USB VBUS powers the CH552E directly. Three switches connect individual GPIO inputs to GND; firmware must enable internal pull-ups and debounce the inputs. A pressed key reads LOW. The status LED is driven by sinking current: VBUS → R3 (1 kΩ) → D1 → LED_K. A LOW output turns it on.

CC1 and CC2 each have an independent 5.1 kΩ pull-down to GND. The USB-C D+ contacts are joined together, as are the D− contacts. U2 provides protection for USB and CC lines. SBU contacts are unused.

C1 bypasses VBUS with 100 nF, C2 bypasses the MCU's V33 pin with 100 nF, and C3 adds 1 µF on VBUS. V33 is the internal regulator bypass node, not an external 3.3 V supply input. The design uses no external crystal or USB series resistors.

### MCU connections

| U1 pin | Signal | Connection |
| --- | --- | --- |
| 1 / P1.4 | LED_K | D1 cathode; active-LOW LED control |
| 2 / P1.5 | KEY_TOP | SW1, upper key |
| 3 / P1.6 | KEY_LEFT | SW2, lower-left key |
| 4 / P1.7 | KEY_RIGHT | SW3, lower-right key |
| 5 | RESET | Reset test pad |
| 6 / P3.6 | USB_DP | USB D+ and protection circuit |
| 7 / P3.7 | USB_DM | USB D− and protection circuit |
| 8 | GND | Ground planes and return connections |
| 9 / VCC | VBUS | USB 5 V supply |
| 10 / V33 | V33 | Internal regulator bypass capacitor C2 |

The schematic was organized by function, with continuous wires showing component-to-MCU connections and proper power and GND symbols. Network names supplement the wires. The power nets are VBUS and V33.

### Component selection

Parts were selected for low cost and available LCSC inventory during design on September 5, 2026. Availability and quantity pricing must be checked again when ordering; assembly-service inventory was not fully verified.

| References | Part / value | Package | LCSC |
| --- | --- | --- | --- |
| U1 | WCH CH552E | MSOP-10 | C967938 |
| U2 | TECH PUBLIC SRV05-4 | SOT-23-6 | C558418 |
| J1 | SHOU HAN TYPE-C16PIN | USB-C, mixed mounting | C393939 |
| SW1–SW3 | HanElectricity CPG151101D13 | MX-compatible, through-hole | C49234235 |
| D1 | YLED0603YG | 0603 | C19171392 |
| R1, R2 | 5.1 kΩ | 0402 | C25905 |
| R3 | 1 kΩ | 0402 | C11702 |
| C1, C2 | 100 nF | 0402 | C1525 |
| C3 | 1 µF | 0402 | C52923 |

U2 replaced an unavailable protection part. All resistors and capacitors are 0402; the LED is 0603. The BOM is the authoritative ordering list for this export.

## Mechanical layout and routing

- Two copper layers; all thirteen components are placed on Top. The intended board thickness is 1.6 mm, to be confirmed in fabrication settings.
- Approximately 55 × 41.24 mm overall. Four tangent R5 mm corners preserve the original edge positions, including the slight slope of the upper edge. Use the Gerber outline for exact geometry.
- No corner mounting holes: the enclosure is intended to retain the PCB with snap fits. Switch-related holes remain.
- Electronics occupy the upper-right area. Keycap rectangles on Top silkscreen are mechanical references; components may occupy their interior where mechanically compatible.
- J1 is at X50, Y31 mm, facing the right edge. D1 is below J1, outside the keycap rectangles, at X50.927, Y22.733 mm. R3 is nearby at X48.006, Y22.733 mm.
- R3 and D1 were routed together to shorten LED wiring. VBUS routing was adjusted around the connector and power loads, with pad escapes constrained by nearby GND clearance.
- Both sides use solid GND pours with isolated islands disabled. Stitching vias connect the layers around the perimeter and circuitry. Added stitching used 0.3 mm drills and 0.6 mm lands; subsequent user edits are retained. Via count was not optimized through EMC measurement.
- User-placed artwork and test pads were preserved. Test pads sit outside the Top logo and away from the buttons, with Top silkscreen labels GND, 5V, 3V3, D+, D−, and RST. They expose GND, VBUS, V33, USB_DP, USB_DM, and RESET respectively.

Coordinates above follow the placement export's board coordinate system. The placement file marks J1 and the three switches as `SMD = No`; J1 has both surface contacts and mechanical anchors. Confirm the intended assembly process and rotations in the assembler's preview.

## Verification and remaining work

During design, netlist checks covered MCU connections, USB polarity, CC resistors, power, switches, and passive footprints. The final saved PCB check after rounding the outline reported zero DRC errors. Geometry checks covered the four R5 arcs, outline closure, and preservation of existing placement and routing.

The schematic check reported zero fatal errors, zero errors, and three warnings concerning the RESET single-pin net, resistor/capacitor attribute standardization, and unused SBU NC marking. These were not represented as a warning-free schematic.

Release-file checks verified ZIP integrity, matching BOM and placement designators, thirteen Top-side components, 0402 passive footprints, four R5 outline arcs, and STEP exchange-file framing. These checks do not replace reviewing the exported layers or checking the assembled board.

Hardware bring-up, the programming/boot procedure, USB behavior, firmware, WebHID configuration, signal quality, ESD performance, and physical keycap/enclosure fit remain to be validated. Review test-pad mask/paste openings and assembly alignment before fabrication.

## Development references

See [PCB development with EasyEDA](../../docs/pcb-development.md) for the workflow used to edit and verify the design. Component decisions were informed by the [WCH CH552 datasheet](https://www.wch-ic.com/downloads/CH552DS1_PDF.html) and supplier data. Schematic organization followed functional grouping and power/ground placement principles from the [KiCad Library Convention](https://klc.kicad.org/).

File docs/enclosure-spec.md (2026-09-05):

# Enclosure and 3D CAD Specification

Status: design requirements, September 6, 2026. The enclosure must be designed in **parametric 3D CAD** and validated with physical prototypes. No finished enclosure model or validated fit is established by the current PCB release.

## Appearance and fixed keycap dimensions

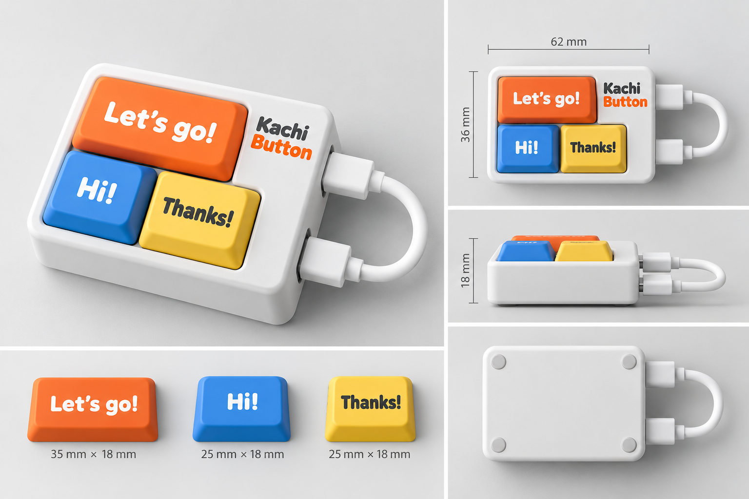
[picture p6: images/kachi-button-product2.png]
Latest product and keycap reference


Use the latest reference for the rounded white body, visible key arrangement, logo beside the upper key, and a cable loop on the right. Use the redesigned logo assets; visual renderings do not define hidden construction details.

| Feature | Dimension / decision | Status |
| --- | --- | --- |
| Upper keycap | 35 × 18 mm in plan view | Confirmed by user |
| Lower-left keycap | 25 × 18 mm in plan view | Confirmed by user |
| Lower-right keycap | 25 × 18 mm in plan view | Confirmed by user |
| Pictured enclosure | 62 × 36 × 18 mm | Provisional visual target only |
| Purchased cable | Nominal 10 cm, USB-C male to male | Confirmed purchase; detailed dimensions TBD |
| PCB retention | Snap fits, no corner PCB screws | Confirmed |

Do not substitute standard “2U / 1U” dimensions for the confirmed keycap sizes. Record which physical keycap edges define the stated dimensions before machining close-fitting openings; cap height, skirt profile, stem location, underside cavity, and travel envelope still need measurement.

The two 18 mm keycap rows already require 36 mm before any gap or surrounding wall. The existing PCB is also approximately 41 mm high. Therefore, the pictured 36 mm external enclosure dimension cannot contain the current board and intended keys. Keep the keycap dimensions and PCB geometry fixed; derive a larger case envelope in CAD. The 62 mm width and 18 mm height also remain unverified, particularly with full-height switch bodies and protruding keycaps.

Specify case-body height and overall height including keycaps separately. Do not reduce switch travel, thin walls arbitrarily, or scale imported PCB geometry to match the rendering.

## CAD inputs and datums

Import the [v1 STEP assembly](../pcb/v1/board-3d-data/3D_PCB1_2026-09-05.step) and align it with the [Gerber outline/drills](../pcb/v1/gerber/Gerber_PCB1_2026-09-05.zip). Use the [PCB placement table](pcb-spec.md) as a cross-check. STEP export and manufacturing data have different timestamps; verify their agreement before using them as mating geometry.

Use millimeters and a documented board-to-case coordinate transform. Define the board top surface as the case assembly's Z datum, with the nominal 1.6 mm board extending below it. Validate that interpretation against the imported model rather than assuming the STEP origin or axis directions.

Measure actual switches, keycaps, plug bodies, strain relief, and assembled underside protrusions. A placement-file origin is not necessarily a stem center or USB aperture center. Model missing features as clearly identified measured reference bodies.

## Construction and retention

Proposed architecture: a lower tray with board support ledges and snap retention, plus an upper frame around the key openings. Part split and fastening between enclosure pieces are CAD decisions, but PCB retention must use snap fits rather than introducing four corner board holes.

Support the PCB where pressing keys and inserting the cable load it. Place supports on verified free regions and keep them away from exposed pads, solder joints, traces, switch pins, and connector anchor protrusions. A Bottom face without mounted components still needs clearance for through-hole leads and solder fillets.

Snap beams need clearance to flex, root fillets, a lead-in, controlled engagement, and an assembly/release path. Select dimensions and material together, then print coupons before committing to the full case. No untested latch geometry, pull force, or cycle life is a fixed specification.

The rendered underside circles may represent feet; they are not permission to add PCB screw holes. Feet are optional pending stability tests. If used, ensure they do not block disassembly or conceal required access.

## Key openings and motion

Locate openings from the actual switch stems and the confirmed keycaps. Verify the upper 35 × 18 mm cap's orientation and stem offset rather than copying the visual center. Preserve the v1 switch placement unless a PCB revision is explicitly approved.

Model each key at rest and at full depression, including skirt motion and tolerances. Allow clearance between adjacent keys and between keys and walls throughout travel. Check off-center presses on the wide cap. Determine whether the selected cap/switch combination requires stabilization; no stabilizer interface is assumed present in v1.

Keycap rectangles on PCB silkscreen are design references, not certified 3D clearance boundaries. Electronics inside them are allowed only when the real moving keycap envelope clears those components. Keep the frame removable enough for assembly and servicing.

## USB opening, LED, and test access

The only electrical USB port is J1, facing the right edge at exported placement X50, Y31 mm. Derive the aperture from its actual shell and the purchased cable's overmold. Allow full insertion without the overmold bottoming on the case; provide finger access for unplugging and account for molding/printing tolerances.

The LED is D1 at exported X50.927, Y22.733 mm below J1. Provide visibility with a suitable opening, translucent region, or light guide. Select the solution in CAD; do not relocate D1 or R3 just to match a concept rendering.

Keep access to the six Top test pads available during assembly or through an intentionally removable cover. Do not place permanent supports on those pads. A service opening in the final enclosure is optional; accessibility before closure is required for programming and bring-up.

## Cable loop and parking holder

Use the purchased white, nominal **10 cm** USB-C cable as the mechanical baseline. See [the cable reference and unknowns](product-spec.md#purchased-cable).

One plug stays inserted into J1; the free plug parks in an **unpowered mechanical holder** to make a loop. The latest image shows two plug bodies on the right side. This supersedes treating the preliminary rear-holder location as fixed. Exact holder position and orientation are determined by CAD and the actual cable.

Do not add a second live connector. The holder should grip an appropriate measured part of the plug body without damaging the metal shell or creating electrical contact. Provide a release motion and finger clearance. Record the usable cable length between strain-relief exits rather than treating “10 cm” as that measurement.

Route the cable with a natural bend, without forcing a kink or persistent side load on J1. Design strain support so normal handling of the loop does not transfer all force to the connector solder joints. Verify insertion, parking, unplugging, and carrying on a physical prototype. If the 10 cm cable cannot form a practical loop with this geometry, report the conflict before changing the purchased cable baseline.

The loop's load capability is not yet established. Do not describe it as a tested keychain attachment until retention and handling checks are completed.

## Parametric dimensions and deliverables

Keep these values in the CAD parameter table rather than scattering them through sketches:

| Parameter group | Inputs |
| --- | --- |
| Board | Exact outline, R5 arcs, thickness, assembly transform |
| Keys | Confirmed plan sizes; measured stem positions, heights, travel, and clearances |
| Case | Wall/base thickness, key gaps, rim height, overall envelope |
| Retention | Latch length/thickness, engagement, root radius, flex clearance |
| USB | Shell aperture, plug overmold clearance, insertion depth, strain support |
| Cable parking | Holder size, location, orientation, cable diameter, bend envelope |
| Manufacturing | Chosen process/material, shrinkage and clearance allowances, print orientation |

Values not yet measured are TBD. Choose a CAD application that preserves editable parametric source and can export STEP and printable meshes; no particular application has been selected. Prototype manufacturing is 3D printing. Material and process selection must support repeatable snap behavior and acceptable surface finish.

Deliver editable CAD source, a parameter table, STEP solids/assembly, STL or 3MF print files, and a dimensioned drawing. Include an exploded assembly view, section views through the switches/USB/latches, print settings, assembly instructions, and the compatible PCB revision. A rendering alone is not the enclosure deliverable.

## Acceptance checks

| Check | Pass condition |
| --- | --- |
| CAD interference | No collisions among board, components, keycaps through travel, case, and cable |
| PCB fit | Board seats without bending and snaps retain it without touching electrical features |
| Key operation | Each cap returns freely and does not contact adjacent caps or the frame |
| USB fit | Purchased plug fully seats and can be removed without case interference |
| Cable storage | Free plug parks/releases; bend and handling do not loosen or visibly stress J1 |
| Assembly/service | Switch leads clear the base; programming/testing is possible before closure |
| Print iteration | Measured clearance and latch performance recorded for the selected printer/material |
| Dimensional release | Final body and overall dimensions replace provisional image dimensions in drawings |

Record test conditions and results, not just “fits.” Repeated snap/parking cycles, drop/handling criteria, and acceptable forces must be defined before a production release; they are not validated by the v1 board preview.

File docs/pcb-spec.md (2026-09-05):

# PCB Specification

Baseline: PCB v1 exported September 5, 2026. See [the release record](../pcb/v1/README.md) for BOM, manufacturing files, and original verification results.

## Geometry and coordinate convention

The board has two copper layers, Top-side component placement, an intended FR-4 material and 1.6 mm thickness, and no corner mounting holes. Retention is by the enclosure's snap fits. Switch and connector mounting holes remain functional features.

The exported outline is 55 mm wide and approximately 41.22 mm high after R5 rounding. The original straight upper edge slopes slightly; do not replace it with an assumed exact 55 × 41 mm rounded rectangle. All four corners are tangent arcs of radius 5 mm. The Gerber outline and drill files define exact XY geometry; confirm board thickness in the fabrication order.

All coordinates below are millimeters in the export's XY frame: X increases to the right and Y toward the upper edge in a Top view. The straight left edge is X=0 and lower edge Y=0; their virtual intersection lies outside the rounded material. Bottom views are mirrored and must not be used to copy Top coordinates.

Placement coordinates are the export's **Mid X / Mid Y** values, with rotations as exported by EasyEDA. They are not automatically the center of a stem, USB mouth, or enclosure cutout. Derive those features from the footprint and 3D model. Use one documented transform when importing the STEP assembly into CAD.

## Exported component placement

| Reference | Function | X (mm) | Y (mm) | Rotation (degrees) |
| --- | --- | --- | --- | --- |
| SW1 | Upper key | 18.000 | 33.800 | 0 |
| SW2 | Lower-left key | 13.970 | 14.800 | 0 |
| SW3 | Lower-right key | 40.000 | 14.800 | 0 |
| J1 | USB-C, faces right | 50.000 | 31.000 | 90 |
| U1 | CH552E | 36.000 | 31.000 | 90 |
| U2 | SRV05-4 protection | 43.000 | 34.000 | 90 |
| D1 | Status LED | 50.927 | 22.733 | 0 |
| R3 | LED resistor | 48.006 | 22.733 | 0 |
| R1 | CC1 pull-down | 39.000 | 37.000 | 0 |
| R2 | CC2 pull-down | 39.000 | 35.000 | 0 |
| C1 | VBUS bypass | 32.500 | 31.500 | 90 |
| C2 | V33 bypass | 32.500 | 29.500 | 90 |
| C3 | VBUS bulk capacitor | 41.000 | 38.500 | 90 |

Source: [v1 pick-and-place workbook](../pcb/v1/gerber/PickAndPlace_PCB1_2026-09-05.xlsx). All thirteen components are on Top. The three switches are through-hole; J1 combines surface contacts with mechanical anchors and is marked `SMD = No` in the export.

The user's placements are the baseline. Electronics are concentrated at upper right. J1 is in the upper half of the board, facing the right edge. D1 is below J1 and outside the keycap rectangles; R3 stays close to D1. Components may occupy a silk keycap rectangle only if their physical heights and the moving keycap remain compatible.

## Power and USB

The board is a **5 V USB-C sink without USB PD negotiation**. R1 and R2 independently connect CC1 and CC2 to GND through 5.1 kΩ. A compliant Type-C source detects the sink and supplies nominal 5 V; this circuit does not request 9, 12, 15, or 20 V. The resistors indicate attachment, not a negotiated power contract. [TI's USB Type-C guide](https://www.ti.com/lit/SLYY228) describes this 5 V sink arrangement.

VBUS feeds U1 VCC directly. There is no external regulator converting a higher input voltage to 5 V, and no PD controller. Power consumption and firmware USB power declarations must remain within the supported USB power budget; the CC resistors alone do not authorize arbitrary current draw.

J1's A6/B6 contacts join USB_DP, and A7/B7 join USB_DM. SBU contacts are unused. U2 protects USB and CC signals. C1 is 100 nF on VBUS, C2 is 100 nF on V33, and C3 is 1 µF on VBUS. V33 is the MCU's internal regulator bypass node, not an external power input.

## MCU and user I/O

| U1 pin | Net | Required function |
| --- | --- | --- |
| 1 / P1.4 | LED_K | LOW turns LED on |
| 2 / P1.5 | KEY_TOP | SW1 input, internal pull-up, pressed LOW |
| 3 / P1.6 | KEY_LEFT | SW2 input, internal pull-up, pressed LOW |
| 4 / P1.7 | KEY_RIGHT | SW3 input, internal pull-up, pressed LOW |
| 5 | RESET | Reset test access |
| 6 / P3.6 | USB_DP | USB D+ |
| 7 / P3.7 | USB_DM | USB D− |
| 8 | GND | Ground |
| 9 / VCC | VBUS | USB 5 V |
| 10 / V33 | V33 | Internal regulator bypass |

Each switch closes its GPIO to GND, without a key matrix or matrix diodes. Firmware provides debounce. The LED current path is VBUS → R3 (1 kΩ) → D1 → LED_K. No external crystal or USB series resistors are populated in v1. Refer to the [WCH CH552 datasheet](https://www.wch-ic.com/downloads/CH552DS1_PDF.html) when implementing reset, GPIO, and USB initialization; RESET must not be treated as a generic active-LOW reset or SWIO connection.

## Parts and routing requirements

The [BOM](../pcb/v1/gerber/BOM_Board1_Schematic1_2026-09-05.xlsx) contains nine part types and thirteen components. It controls exact procurement identifiers: CH552E C967938; TYPE-C16PIN C393939; CPG151101D13 C49234235; YLED0603YG C19171392; SRV05-4 C558418; and the resistor/capacitor entries in the workbook. All resistors and capacitors are 0402; D1 is 0603. The stocked TECH PUBLIC ESD part replaced the unavailable earlier candidate.

Use continuous schematic wires to show all component-to-MCU connections, functional grouping, and genuine power/GND symbols with correct net attributes. Preserve netlist connectivity when improving readability.

Both Top and Bottom have solid GND pours, with isolated islands disabled. Stitching vias connect both layers around the circuitry and perimeter; added stitching used 0.3 mm holes and 0.6 mm lands. The final count includes subsequent user changes and is not an EMC-optimized number.

Keep USB routes short with a continuous GND return, avoid unnecessary vias, and review the exported routes rather than assuming automatic routing achieves impedance control. Keep VBUS routing direct and suitably wide while respecting pad escapes and nearby GND clearance. R3–D1 routing should remain short. Rebuild pours after routing/outline changes and run DRC through the [EasyEDA development workflow](pcb-development.md).

## Test access and silkscreen

Six exposed Top pads provide GND, VBUS, V33, USB_DP, USB_DM, and RESET. Their labels are GND, 5V, 3V3, D+, D−, and RST. Preserve the user's locations outside the Top logo and away from the buttons; a straight row is not required.

| Net | Label | X (mm) | Y (mm) |
| --- | --- | --- | --- |
| VBUS | 5V | 34.163 | 38.354 |
| V33 | 3V3 | 34.036 | 28.575 |
| GND | GND | 30.099 | 37.084 |
| USB_DP | D+ | 34.671 | 34.671 |
| USB_DM | D− | 43.815 | 26.162 |
| RESET | RST | 36.449 | 33.528 |

These pad positions are from the final design-session snapshot, not the component placement workbook. Nominal pad diameter is 1.016 mm. Check the actual manufactured openings before designing a pogo-pin fixture. Labels were placed with nominal 1 mm height and 0.15 mm strokes. Preserve artwork on both faces and avoid label overlap with exposed copper.

## Manufacturing and acceptance

Release directories are `pcb/v1/gerber/`, `pcb/v1/board-3d-data/`, and `pcb/v1/images/`. Native editable project data is not included in that release. The Gerber, placement, and STEP exports have differing timestamps; reconcile their revision before changing mechanical interfaces.

Design-session checks reported PCB DRC zero errors; schematic checks reported zero fatal/errors and three warnings. Those warnings and remaining prototype checks are documented in the v1 release record. New changes require netlist checks, DRC, regenerated pours, outline checks, and assembly preview review.

Bring-up must verify VBUS/GND isolation, nominal 5 V input, MCU operation, all three switches, LED polarity, programming access, and USB behavior with the purchased cable. DRC does not establish USB signal quality, ESD performance, case fit, or working firmware.

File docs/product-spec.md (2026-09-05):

# Product Specification

Status: requirements baseline, September 6, 2026. See [the specification index](README.md) for authority and unresolved decisions.

## Purpose and appearance

Kachi Button is a compact programmable USB keyboard that turns frequently used words and shortcuts into physical buttons. The mechanical click is part of the experience. “Kachi” refers to the sound of a click.

The core message is: **Click once. Type the whole thing.**

Latest Kachi Button product reference

This is the latest appearance reference. It shows a rounded white enclosure, an orange upper key, blue and yellow lower keys, a logo beside the upper key, and a short cable loop on the right. Colors and printed legends are a presentation baseline; key mappings remain configurable.

The user confirmed the keycap dimensions shown in this image: upper 35 × 18 mm and lower two each 25 × 18 mm. The pictured enclosure dimensions are provisional. See [the enclosure specification](enclosure-spec.md) for the resulting fit constraints.

Use the redesigned assets under `images/logo/` and the editable `images/kachi-button.sketch` source. The repository's main README uses `kachi-button-text-white-background.png` as its header logo. Preserve the existing PCB artwork separately from enclosure branding.

## Users and example actions

| Context | Example |
| --- | --- |
| Game chat | Send “Hi!”, “Thanks!”, or “Let's go!” after the user focuses the chat field |
| AI conversations | Send “OK”, “Continue.”, or “Yes, do it.” |
| Everyday shortcuts | Map a key, modifier shortcut, or short text to a physical button |
| Maker demonstration | Choose keycaps, configure phrases in the browser, and use them immediately |

The device types into the host's focused application. It does not detect the active application or automatically open a game chat field in the initial release. Sending Enter is an explicit mapping option, not an implicit suffix on every phrase.

## Required experience

1. Connect the device to a USB host with a data-capable cable.
2. The host recognizes a standard HID keyboard; normal typing does not require a companion application.
3. Open the configuration page in a supported desktop browser and select **Connect Kachi Button**.
4. Choose the device through the browser's permission UI.
5. Edit the mappings using physical labels **Top**, **Lower left**, and **Lower right**.
6. Save explicitly and show success only after the device confirms persistence.
7. Close the page. The device continues using its saved mappings while powered by the host.

“Standalone” means the browser is unnecessary after configuration. It does not mean battery-powered or able to type without a host. The product has no battery, charging circuit, Bluetooth, or Wi-Fi.

## Scope and milestones

| Milestone | Required outcome |
| --- | --- |
| Hardware bring-up | Verify power, programming, three inputs, LED polarity, and USB keyboard enumeration on v1 |
| Initial typing demonstration | One debounced press emits one fixed text action; no stuck modifiers or unintended startup typing |
| Configurable prototype | Composite keyboard/vendor HID, three persistent mappings, browser read/edit/save/reset flow |
| Mechanical prototype | Parametric CAD, printed enclosure, working snap fits, key travel, connector access, and cable parking |
| Product validation | Combined use on target hosts, power cycles, configuration failures, and repeated mechanical handling |

Initial configurable text targets 32 ASCII bytes per key using a US keyboard layout. The product roadmap also includes single keys, shortcuts, and text followed by Enter. Double presses, long presses, multi-step scripts, Unicode/emoji typing, wireless operation, and battery power are outside the initial scope. See [firmware requirements](firmware-spec.md) for staging and technical limits.

Windows, macOS, and Linux are keyboard compatibility targets. Android keyboard use is a later host/cable compatibility test, not a promise of Android WebHID support. Browser support and host permission requirements must be tested separately.

## Purchased cable

The user purchased a **nominal 10 cm USB-C male-to-USB-C male cable**, reported September 6, 2026. The supplied reference shows a white cable, straight male plugs with white molded bodies, and a flexible section bent into a U. This replaces the original 15–20 cm cable concept.

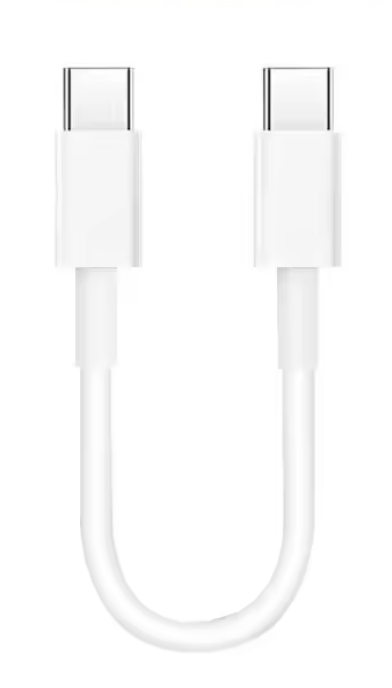
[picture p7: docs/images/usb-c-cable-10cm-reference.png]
Purchased cable appearance reference


The image is a user-supplied appearance reference, not a dimensional drawing or an electrical datasheet. Manufacturer, SKU, whether the stated length includes the plugs, data capability, overmold dimensions, and bend radius are not yet verified.

USB 2.0 data operation is required. Confirm enumeration and typing with the purchased cable; a charge-only cable cannot satisfy the product requirement. Do not assume data support or a particular PD rating from the image.

During storage, one plug stays connected to J1 and the other parks in an unpowered holder on the enclosure to form a loop. The latest product image places both plug bodies on the right side. The second opening is a mechanical parking feature, not a second electrical USB port. Its final location depends on fitting the actual 10 cm cable without stressing the connector.

## Cost and validation

Use low-cost stocked parts, Top-side assembly, and standard PCB fabrication where possible. Recheck all part numbers, order-quantity pricing, and assembly inventory before purchasing. The earlier 30–50 prototype and 50–100 event-unit quantities are planning estimates, not purchase commitments.

A prototype is accepted only when it can connect, type once per press, save and retain mappings, fit its enclosure, and park/unpark the purchased cable without binding. Hardware exports and renderings alone do not satisfy these criteria.

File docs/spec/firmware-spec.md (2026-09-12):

# Firmware and Configuration Specification

Status: configurable-release requirements and proposed baseline, September 6, 2026. The September 12 [firmware](../../firmware/README.md) implements configurable ASCII macros, repeat counts, ms intervals, DataFlash persistence, and host-initiated ISP via USB vendor control requests on a keyboard interface; see its [validation record](../../firmware/bring-up.md) for verification status. The proposed vendor HID interface and configuration website remain unimplemented. See [product requirements](product-spec.md) and [the PCB pin map](pcb-spec.md).

## Platform and build

Target the WCH CH552E on PCB v1. Use its internal clock and native USB peripheral. CH55xduino and an SDCC-based implementation are candidates from the concept phase; select a toolchain after proving USB descriptors, bootloader compatibility, code size, RAM use, and nonvolatile storage access. QMK compatibility is not a requirement.

Keep pin assignments, debounce timing, limits, and USB identifiers in a shared configuration module appropriate to the firmware language. Record toolchain/library versions and a reproducible build command. Retain a linker map and memory-budget summary with release builds.

Do not derive application flash capacity from the total advertised chip memory without accounting for the bootloader and reserved regions. Resolve exact erase/write semantics and available data storage against the [WCH documentation](https://www.wch-ic.com/downloads/CH552DS1_PDF.html) and selected toolchain before implementing persistence.

## Startup and key scanning

Initialize P1.5, P1.6, and P1.7 as pulled-up inputs for Top, Lower left, and Lower right. A closure to GND is a press. Initialize P1.4 to the inactive LED state; LOW lights D1.

Load a valid saved configuration or documented defaults, then enumerate USB. Do not emit keyboard input just because the device was plugged in, resumed, reset, or configured. Require a release before accepting a key already held at startup.

Implement nonblocking per-key debounce and keep USB servicing responsive. A 10–20 ms stable interval is the initial tuning range, not a validated switch measurement. One debounced press produces one action; holding the button does not repeatedly launch text. Rearm after a debounced release. Multi-click and long-press recognition are deferred.

Proposed initial concurrency policy: execute one action at a time and ignore new presses while it is active, requiring release before rearming those keys. Document and test this bounded behavior rather than allowing partial actions to interleave. Revisit only if user testing establishes a need for queuing.

## Actions and mapping

| Stage | Supported behavior |
| --- | --- |
| Bring-up | Fixed text on each key, no persistent configuration dependency |
| Initial configurable release | Three text mappings, each up to 32 ASCII bytes; optional explicit Enter suffix |
| Subsequent extension | Single HID keys and modifier shortcuts using a versioned action type |
| Deferred | Multi-step scripts, Unicode/emoji, double/long press, and application-specific automation |

Use the latest product image for the proposed demonstration defaults: Top = `Let's go!`, Lower left = `Hi!`, Lower right = `Thanks!`. This physical order differs from earlier numbered examples. Default phrases and legends are editable, not hardwired identities. The AI preset is `OK`, `Continue.`, and `Yes, do it.` in the same physical order.

Target printable US-layout ASCII for text. The host must use a matching keyboard layout; clearly disclose this in the UI. Reject unsupported characters rather than silently corrupting text. Unicode input methods and arbitrary host layout conversion are outside the initial release.

Generate complete key-down/modifier and release reports for each character or shortcut. Always clear modifiers and pressed keys at action completion or cancellation while connected. On disconnect, discard pending actions and restart in an all-released state. Respect endpoint readiness rather than emitting reports with unbounded blocking delays. Test capitalization, punctuation, repeated letters, and rapid button presses.

## USB interfaces

The configurable target is a composite HID device with two interfaces:

| Interface | Purpose |
| --- | --- |
| 0: HID Keyboard | Normal host keyboard input |
| 1: Vendor-defined HID | Read, edit, and persist device configuration through WebHID |

The vendor collection must be separate from keyboard usage collections. Chrome restricts direct website access to protected keyboard collections; its [WebHID guide](https://developer.chrome.com/docs/capabilities/hid) documents the distinction and device selection/report APIs.

Define the complete descriptors and endpoint allocation after checking the selected USB stack and CH552E resource limits. VID/PID, usage page/usage, report IDs, endpoint numbers, polling intervals, protocol version, and exact byte layout are TBD implementation deliverables, not established by the concept's example commands.

Target reports no larger than 64 bytes, subject to the descriptor and stack constraints. Specify whether a stated size includes the report ID. A full three-key configuration may require multiple transfers; do not assume three 32-byte strings fit in one report. Normal keyboard operation must continue without a browser connection.

The device consumes 5 V USB power without PD negotiation. Validate descriptor power declarations, suspend behavior, and measured current; do not enable remote wake unless explicitly implemented and tested.

## Configuration operations

The following operation names describe semantics, not a frozen binary protocol:

| Operation | Required semantics |
| --- | --- |
| GET_INFO | Return firmware/protocol version, supported action types, and limits |
| GET_CONFIG | Read current mappings and persistence state |
| SET_KEY | Validate key index, action type, length, and content; stage an edit without writing flash |
| SAVE_CONFIG | Validate the complete staged configuration, persist it, and acknowledge only after verification |
| RESET_CONFIG | Explicitly restore documented defaults; UI confirms this user action |

Use bounded payloads and reject malformed, oversized, unsupported-version, and invalid-index requests. Each request needs an unambiguous success or error result. Define transaction correlation, timeouts, reconnect behavior, and retries before freezing the protocol. Retrying a save must not unexpectedly multiply flash writes. Editing/saving must not itself type the configured phrase.

## Persistence

The target payload is three mappings of up to 32 bytes each, plus lengths, action metadata, format version, and integrity information. Build an explicit byte budget for the real writable region. Do not assume there is space for two complete configuration copies or general wear leveling.

Write only on explicit Save or reset, not every keystroke or switch press. Validate lengths and integrity before accepting stored bytes. Corrupt or unsupported records must fall back to defaults without unsolicited typing. Specify the power-loss behavior: never execute a partially written mapping; after interruption, recover either a valid configuration or known defaults. Whether the previous configuration survives an interrupted save depends on the selected storage method and must be tested.

## Browser configuration

Provide a hosted configuration page with three physical-position fields, a clear ASCII limit, connection state, unsaved-change indication, Save, and reset-to-defaults. Do not assume a deployment domain has been selected from the concept examples.

Require a secure context, check WebHID availability, and start device selection from a user interaction. Filter using the implemented device identifiers and vendor collection; verify the protocol before enabling editing. Device identifiers select compatible hardware but are not authentication credentials.

On connection, read the current configuration. On Save, stage changes, request persistence, and read back before showing success. Preserve or clearly explain unsaved edits after cancellation, device removal, permission refusal, or write failure. The user must be able to close the browser after a successful save and retain normal operation. Test Linux host access permissions as part of the supported-platform matrix rather than promising universal zero-setup browser access.

## Status LED

Proposed pattern baseline: off during startup/unconfigured USB; steady on while USB is configured; brief off pulse after an accepted key action; slow blink while an explicit configuration transaction is active. Resolve timing in firmware and ensure LED updates never block USB. Suspend should extinguish the indicator unless the validated power budget permits otherwise.

These are proposed state meanings, not behavior demonstrated by the current PCB. Save success must also be reported in the UI; the LED is not the sole persistence confirmation.

## Programming and acceptance

Validate the CH552E boot-entry method and compatible flashing tool on actual hardware. The PCB exposes RESET and USB test pads, not an SWIO debug port. Do not invent a reset polarity or boot-button sequence from another MCU family. Document fixture wiring, voltage levels, recovery, and programming steps once proven.

| Test | Pass condition |
| --- | --- |
| Enumeration | Correct keyboard and vendor interfaces on targeted desktop hosts |
| Inputs | Correct physical mapping, one action per press, debounce and startup-held-key behavior |
| Reports | Text, repeated characters, case, and explicit Enter match expectations; modifiers release |
| Persistence | Three maximum-length mappings survive unplug/replug and browser closure |
| Invalid input | Bad reports and unsupported text are rejected without corruption or input emission |
| Interrupted save | Reconnect yields a valid configuration or defaults, never partial text |
| Browser lifecycle | Permission refusal, disconnect, reconnect, and save errors have clear outcomes |
| Power/cable | Purchased 10 cm cable supports enumeration and stable use; suspend current is verified |

Unit tests should cover mapping, debounce, report sequencing, validation, and stored-record decoding. USB and persistence tests on real hardware are required in addition to host-side tests.

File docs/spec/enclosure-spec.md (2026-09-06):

# Enclosure and 3D CAD Specification

Status: design requirements, September 6, 2026. The enclosure must be designed in **parametric 3D CAD** and validated with physical prototypes. A Fusion PLA prototype now exists; physical fit remains unvalidated. See the [prototype design record and exports](../../3d-models/enclosure-pla-v1/README.md) for the current geometry and printing notes.

## Appearance and fixed keycap dimensions

Latest product and keycap reference

Use the latest reference for the rounded white body, visible key arrangement, logo beside the upper key, and a cable loop on the right. Use the redesigned logo assets; visual renderings do not define hidden construction details.

| Feature | Dimension / decision | Status |
| --- | --- | --- |
| Upper keycap | 33 × 18 mm in plan view | Confirmed by user |
| Lower-left keycap | 25 × 18 mm in plan view | Confirmed by user |
| Lower-right keycap | 25 × 18 mm in plan view | Confirmed by user |
| Pictured enclosure | 62 × 36 × 18 mm | Provisional visual target only |
| Purchased cable | Nominal 10 cm, USB-C male to male | Confirmed purchase; detailed dimensions TBD |
| PCB retention | Snap fits, no corner PCB screws | Confirmed |

The upper width is revised from 35 mm to 33 mm (25 + 4 × 2). All three keycaps are 10 mm high. The central underside stem boss is restored to 6 mm in outer diameter after the 7 mm version interfered with the switch. The cross socket is reduced from 1.5 mm to 1.35 mm arm width, with a 4.25 mm span and 4.5 mm blind depth, following loose-fit feedback. See the [fit revision and source comparisons](../../3d-models/KEYCAP-FIT.md). White SVG lettering remains a separate 0.4 mm-thick body set. Physical switch fit and print tolerances still require testing.

The current lettered Fusion models use the updated path artwork from `images/key-top/kety-top-go-go.svg`, `key-top-hi.svg`, and `key-top-thx.svg`. The upper model is now named `KachiButton-Keycap-Go-go-33x18x10`. The SVG paths, including punctuation and capitalization, define the printed legends; stale SVG title metadata does not. Lettering is centered and remains a separate white 0.4 mm inlay. The two blank samples use the same revised stem boss and socket dimensions.

Two blank print samples are saved in the Fusion `kachi-button` folder: `KachiButton-Keycap-Sample-Blank-33x18x10` and `KachiButton-Keycap-Sample-Blank-25x18x10`. Each is a single solid with no lettering or lettering recess, using the revised 6 mm stem boss and 1.35 × 4.25 mm cross socket. Both models passed dimension and feature-health checks; physical print fit remains untested.

Do not substitute standard “2U / 1U” dimensions for the confirmed keycap sizes. Record which physical keycap edges define the stated dimensions before machining close-fitting openings; skirt profile, stem location, underside cavity, and travel envelope still need measurement.

The two 18 mm keycap rows already require 36 mm before any gap or surrounding wall. The existing PCB is also approximately 41 mm high. Therefore, the pictured 36 mm external enclosure dimension cannot contain the current board and intended keys. Keep the keycap dimensions and PCB geometry fixed; derive a larger case envelope in CAD. The 62 mm width and 18 mm height also remain unverified, particularly with full-height switch bodies and protruding keycaps.

Specify case-body height and overall height including keycaps separately. Do not reduce switch travel, thin walls arbitrarily, or scale imported PCB geometry to match the rendering.

## CAD inputs and datums

Import the [v1 STEP assembly](../../pcb/v1/board-3d-data/3D_PCB1_2026-09-05.step) and align it with the [Gerber outline/drills](../../pcb/v1/gerber/Gerber_PCB1_2026-09-05.zip). Use the [PCB placement table](pcb-spec.md) as a cross-check. STEP export and manufacturing data have different timestamps; verify their agreement before using them as mating geometry.

Use millimeters and a documented board-to-case coordinate transform. Define the board top surface as the case assembly's Z datum, with the nominal 1.6 mm board extending below it. Validate that interpretation against the imported model rather than assuming the STEP origin or axis directions.

Measure actual switches, keycaps, plug bodies, strain relief, and assembled underside protrusions. A placement-file origin is not necessarily a stem center or USB aperture center. Model missing features as clearly identified measured reference bodies.

## Construction and retention

Current prototype architecture: Top is a box with internal latch pockets; Bottom is a plate with lateral flexure latches entirely below the PCB. Two broad front wedges on lateral springs and two fixed rear tabs engage Top pockets below the PCB. Bottom supports and five 3 mm-wide Top ribs extending continuously to the side walls retain the PCB without hooks above the board or screws. A 4 × 5 mm Bottom pad supports the PCB directly beneath J1. A fifth Bottom support, 3 × 2.4 mm at board X48–51 and Y37.8–40.2 mm, pairs with a rear-wall Top rib to retain the previously unsupported rear-right corner. Assemble the case with keycaps removed; the angled assembly path and PLA latch life require physical testing. The compact footprint is 63.3 × 47.2 mm; the 23.25 mm case height excludes the protruding keycaps. The top surface is 3 mm above the keycap lower edges. Top has R2.5 outer edge rounding and the plan outline has R6 corners.

Support the PCB where pressing keys and inserting the cable load it. Place supports on verified free regions and keep them away from exposed pads, solder joints, traces, switch pins, and connector anchor protrusions. A Bottom face without mounted components still needs clearance for through-hole leads and solder fillets.

Snap beams need clearance to flex, root fillets, a lead-in, controlled engagement, and an assembly/release path. Select dimensions and material together, then print coupons before committing to the full case. No untested latch geometry, pull force, or cycle life is a fixed specification.

The rendered underside circles may represent feet; they are not permission to add PCB screw holes. Feet are optional pending stability tests. If used, ensure they do not block disassembly or conceal required access.

## Key openings and motion

Locate openings from the actual switch stems and the confirmed keycaps. Verify the upper 33 × 18 mm cap's orientation and stem offset rather than copying the visual center. Preserve the v1 switch placement unless a PCB revision is explicitly approved.

Model each key at rest and at full depression, including skirt motion and tolerances. Allow clearance between adjacent keys and between keys and walls throughout travel. Check off-center presses on the wide cap. Determine whether the selected cap/switch combination requires stabilization; no stabilizer interface is assumed present in v1.

Keycap rectangles on PCB silkscreen are design references, not certified 3D clearance boundaries. Electronics inside them are allowed only when the real moving keycap envelope clears those components. Keep the frame removable enough for assembly and servicing.

## USB opening, LED, and test access

The only electrical USB port is J1, facing the right edge at exported placement X50, Y31 mm. Derive the aperture from its actual shell and the purchased cable's overmold. Allow full insertion without the overmold bottoming on the case; provide finger access for unplugging and account for molding/printing tolerances.

The LED is D1 at exported X50.927, Y22.733 mm below J1. Provide visibility with a suitable opening, translucent region, or light guide. Select the solution in CAD; do not relocate D1 or R3 just to match a concept rendering.

Keep access to the six Top test pads available during assembly or through an intentionally removable cover. Do not place permanent supports on those pads. A service opening in the final enclosure is optional; accessibility before closure is required for programming and bring-up.

## Cable loop and parking holder

Use the purchased white, nominal **10 cm** USB-C cable as the mechanical baseline. See [the cable reference and unknowns](product-spec.md#purchased-cable).

One plug stays inserted into J1; the free plug parks in an **unpowered mechanical holder** to make a loop. The latest image shows two plug bodies on the right side. This supersedes treating the preliminary rear-holder location as fixed. Exact holder position and orientation are determined by CAD and the actual cable.

Do not add a second live connector. The holder should grip an appropriate measured part of the plug body without damaging the metal shell or creating electrical contact. Provide a release motion and finger clearance. Record the usable cable length between strain-relief exits rather than treating “10 cm” as that measurement.

Route the cable with a natural bend, without forcing a kink or persistent side load on J1. Design strain support so normal handling of the loop does not transfer all force to the connector solder joints. Verify insertion, parking, unplugging, and carrying on a physical prototype. If the 10 cm cable cannot form a practical loop with this geometry, report the conflict before changing the purchased cable baseline.

The loop's load capability is not yet established. Do not describe it as a tested keychain attachment until retention and handling checks are completed.

## Parametric dimensions and deliverables

Keep these values in the CAD parameter table rather than scattering them through sketches:

| Parameter group | Inputs |
| --- | --- |
| Board | Exact outline, R5 arcs, thickness, assembly transform |
| Keys | Confirmed plan sizes; measured stem positions, heights, travel, and clearances |
| Case | Wall/base thickness, key gaps, rim height, overall envelope |
| Retention | Latch length/thickness, engagement, root radius, flex clearance |
| USB | Shell aperture, plug overmold clearance, insertion depth, strain support |
| Cable parking | Holder size, location, orientation, cable diameter, bend envelope |
| Manufacturing | Chosen process/material, shrinkage and clearance allowances, print orientation |

Values not yet measured are TBD. Choose a CAD application that preserves editable parametric source and can export STEP and printable meshes; Fusion is used for the current prototype. Prototype manufacturing is 3D printing. Material and process selection must support repeatable snap behavior and acceptable surface finish.

Deliver editable CAD source, a parameter table, STEP solids/assembly, STL or 3MF print files, and a dimensioned drawing. Include an exploded assembly view, section views through the switches/USB/latches, print settings, assembly instructions, and the compatible PCB revision. A rendering alone is not the enclosure deliverable.

## Acceptance checks

| Check | Pass condition |
| --- | --- |
| CAD interference | No collisions among board, components, keycaps through travel, case, and cable |
| PCB fit | Board seats without bending and snaps retain it without touching electrical features |
| Key operation | Each cap returns freely and does not contact adjacent caps or the frame |
| USB fit | Purchased plug fully seats and can be removed without case interference |
| Cable storage | Free plug parks/releases; bend and handling do not loosen or visibly stress J1 |
| Assembly/service | Switch leads clear the base; programming/testing is possible before closure |
| Print iteration | Measured clearance and latch performance recorded for the selected printer/material |
| Dimensional release | Final body and overall dimensions replace provisional image dimensions in drawings |

Record test conditions and results, not just “fits.” Repeated snap/parking cycles, drop/handling criteria, and acceptable forces must be defined before a production release; they are not validated by the v1 board preview.

## FDM structural revision

The current enclosure uses 2 mm rear tab roots and tabs, 2 mm front latch shoulders, and 10 mm-long springs with a 2 × 2 mm cross section. Pocket lower lips are 1.5 mm front and 1.7 mm rear. The nominal roof is 2.4 mm, retaining 2 mm beneath the logo inlays. USB surrounding walls are 2 mm; the blind parking depth is reduced to 3.75 mm. Right-side Top stops are retracted 0.7 mm toward the wall for additional key clearance. See the prototype record for geometry checks and the outstanding printed snap-fit evaluation.

Bottom PCB support posts have a minimum nominal thickness of 2.4 mm: three 2.4 × 3 mm posts, one 3 × 2.4 mm corner post, and the 4 × 5 mm USB support. Their height remains 4.7 mm.

The latest wall requirement is 1.5 mm for ordinary side walls and 2 mm for the Bottom plate. Snap receiver regions retain local reinforcement; the roof, USB regions, and PCB support thicknesses remain as recorded above.

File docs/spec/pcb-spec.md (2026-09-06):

# PCB Specification

Baseline: PCB v1 exported September 5, 2026. See [the release record](../../pcb/v1/README.md) for BOM, manufacturing files, and original verification results.

## Geometry and coordinate convention

The board has two copper layers, Top-side component placement, an intended FR-4 material and 1.6 mm thickness, and no corner mounting holes. Retention is by the enclosure's snap fits. Switch and connector mounting holes remain functional features.

The exported outline is 55 mm wide and approximately 41.22 mm high after R5 rounding. The original straight upper edge slopes slightly; do not replace it with an assumed exact 55 × 41 mm rounded rectangle. All four corners are tangent arcs of radius 5 mm. The Gerber outline and drill files define exact XY geometry; confirm board thickness in the fabrication order.

All coordinates below are millimeters in the export's XY frame: X increases to the right and Y toward the upper edge in a Top view. The straight left edge is X=0 and lower edge Y=0; their virtual intersection lies outside the rounded material. Bottom views are mirrored and must not be used to copy Top coordinates.

Placement coordinates are the export's **Mid X / Mid Y** values, with rotations as exported by EasyEDA. They are not automatically the center of a stem, USB mouth, or enclosure cutout. Derive those features from the footprint and 3D model. Use one documented transform when importing the STEP assembly into CAD.

## Exported component placement

| Reference | Function | X (mm) | Y (mm) | Rotation (degrees) |
| --- | --- | --- | --- | --- |
| SW1 | Upper key | 18.000 | 33.800 | 0 |
| SW2 | Lower-left key | 13.970 | 14.800 | 0 |
| SW3 | Lower-right key | 40.000 | 14.800 | 0 |
| J1 | USB-C, faces right | 50.000 | 31.000 | 90 |
| U1 | CH552E | 36.000 | 31.000 | 90 |
| U2 | SRV05-4 protection | 43.000 | 34.000 | 90 |
| D1 | Status LED | 50.927 | 22.733 | 0 |
| R3 | LED resistor | 48.006 | 22.733 | 0 |
| R1 | CC1 pull-down | 39.000 | 37.000 | 0 |
| R2 | CC2 pull-down | 39.000 | 35.000 | 0 |
| C1 | VBUS bypass | 32.500 | 31.500 | 90 |
| C2 | V33 bypass | 32.500 | 29.500 | 90 |
| C3 | VBUS bulk capacitor | 41.000 | 38.500 | 90 |

Source: [v1 pick-and-place workbook](../../pcb/v1/gerber/PickAndPlace_PCB1_2026-09-05.xlsx). All thirteen components are on Top. The three switches are through-hole; J1 combines surface contacts with mechanical anchors and is marked `SMD = No` in the export.

The user's placements are the baseline. Electronics are concentrated at upper right. J1 is in the upper half of the board, facing the right edge. D1 is below J1 and outside the keycap rectangles; R3 stays close to D1. Components may occupy a silk keycap rectangle only if their physical heights and the moving keycap remain compatible.

## Power and USB

The board is a **5 V USB-C sink without USB PD negotiation**. R1 and R2 independently connect CC1 and CC2 to GND through 5.1 kΩ. A compliant Type-C source detects the sink and supplies nominal 5 V; this circuit does not request 9, 12, 15, or 20 V. The resistors indicate attachment, not a negotiated power contract. [TI's USB Type-C guide](https://www.ti.com/lit/SLYY228) describes this 5 V sink arrangement.

VBUS feeds U1 VCC directly. There is no external regulator converting a higher input voltage to 5 V, and no PD controller. Power consumption and firmware USB power declarations must remain within the supported USB power budget; the CC resistors alone do not authorize arbitrary current draw.

J1's A6/B6 contacts join USB_DP, and A7/B7 join USB_DM. SBU contacts are unused. U2 protects USB and CC signals. C1 is 100 nF on VBUS, C2 is 100 nF on V33, and C3 is 1 µF on VBUS. V33 is the MCU's internal regulator bypass node, not an external power input.

## MCU and user I/O

| U1 pin | Net | Required function |
| --- | --- | --- |
| 1 / P1.4 | LED_K | LOW turns LED on |
| 2 / P1.5 | KEY_TOP | SW1 input, internal pull-up, pressed LOW |
| 3 / P1.6 | KEY_LEFT | SW2 input, internal pull-up, pressed LOW |
| 4 / P1.7 | KEY_RIGHT | SW3 input, internal pull-up, pressed LOW |
| 5 | RESET | Reset test access |
| 6 / P3.6 | USB_DP | USB D+ |
| 7 / P3.7 | USB_DM | USB D− |
| 8 | GND | Ground |
| 9 / VCC | VBUS | USB 5 V |
| 10 / V33 | V33 | Internal regulator bypass |

Each switch closes its GPIO to GND, without a key matrix or matrix diodes. Firmware provides debounce. The LED current path is VBUS → R3 (1 kΩ) → D1 → LED_K. No external crystal or USB series resistors are populated in v1. Refer to the [WCH CH552 datasheet](https://www.wch-ic.com/downloads/CH552DS1_PDF.html) when implementing reset, GPIO, and USB initialization; RESET must not be treated as a generic active-LOW reset or SWIO connection.
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

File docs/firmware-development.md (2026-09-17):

# Keyboard firmware development

Operational guide for CH552E PCB v1, updated September 17, 2026.
Commands below run from the repository root. See the [feature inventory](firmware-features.md)
for current behavior and [internals](firmware-internals.md) for the implementation.

## Prerequisites

| Tool | Version / purpose |
| --- | --- |
| Python | Python 3, host tools and build orchestration |
| Native C compiler | `cc`, portable regression tests |
| Arduino CLI | Tested 1.3.1 |
| CH55xduino | Pinned 0.0.26; SDCC build.13407_4, MCS51Tools 2026.07.10 |
| wchisp | Tested 0.3.0 at `cefd8707df345f1fbd7795e15367281f440bbf05` |
| libusb | Shared library; macOS requires 1.0.30 or newer |

Install the pinned Arduino core using the [build instructions](../firmware/README.md#build-and-test).
Point these variables at your installed tools when they are outside default paths:

```sh
export ARDUINO_DIRECTORIES_DATA="/path/to/arduino-data"
export KACHI_LIBUSB="/path/to/libusb-1.0.dylib"
```

Use a libusb library matching the Python process architecture. The host tools
reject macOS libusb older than 1.0.30 before opening USB: 1.0.29 deadlocked during
the observed detach/exit sequence. See the [hardware record](../firmware/bring-up.md).
Changing the library path does not require changing or reflashing device firmware.
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

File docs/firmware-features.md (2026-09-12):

# Keyboard firmware feature inventory

Implemented behavior for CH552E PCB v1, updated September 12, 2026.
This inventory describes the current code. The [product specifications](spec/firmware-spec.md)
also include future requirements; those are not automatically implemented features.

## Key assignments and limits
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

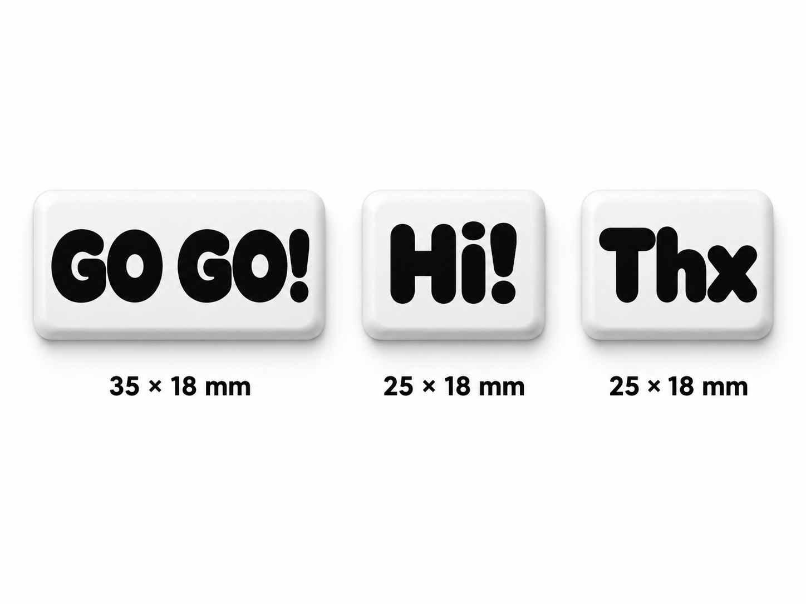
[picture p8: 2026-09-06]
images/key-cap/key-cap.png

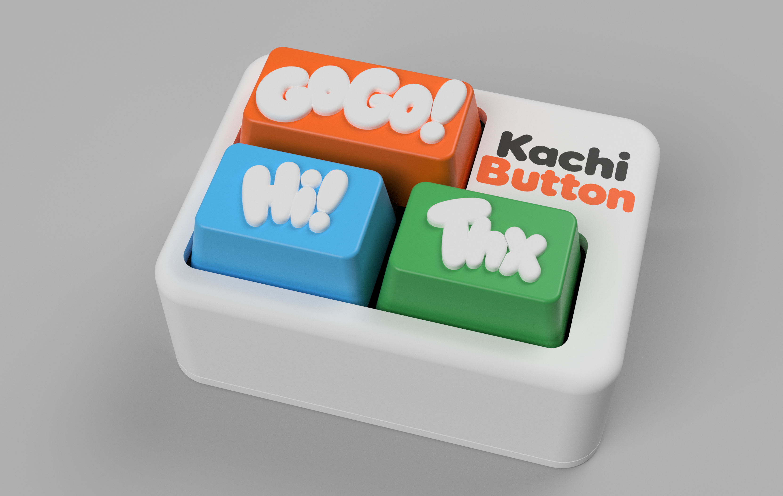
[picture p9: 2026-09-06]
images/enclosure/KachiButton-Enclosure-PLA-v1-2.png

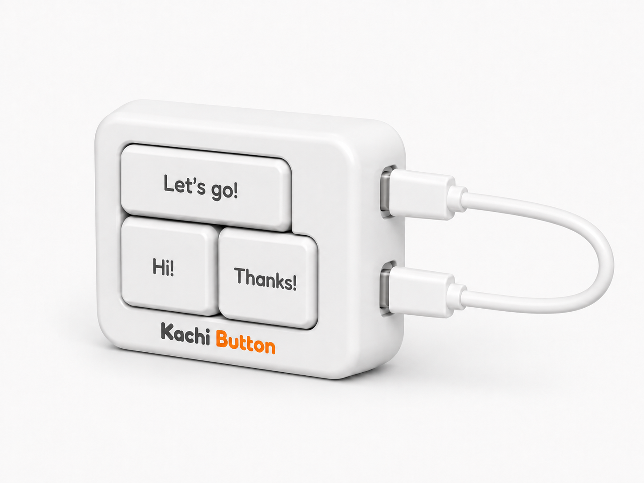
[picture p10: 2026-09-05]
images/kachi-button-product.png

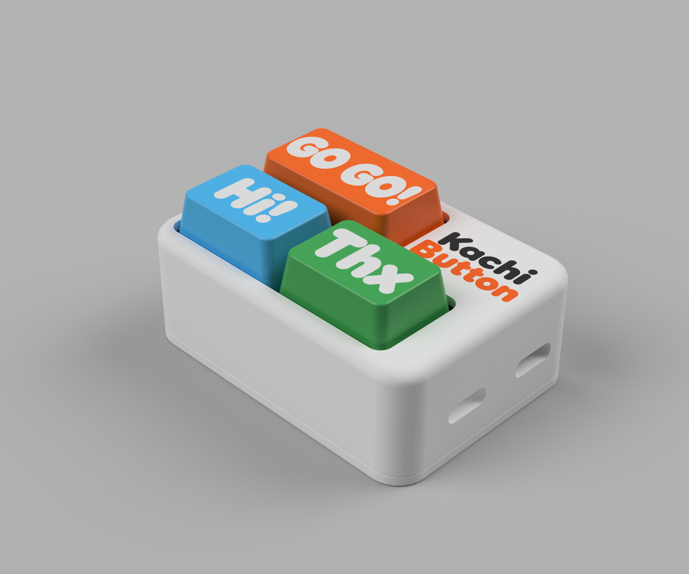
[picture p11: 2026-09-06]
images/enclosure/KachiButton-Enclosure-PLA-v1-1.png

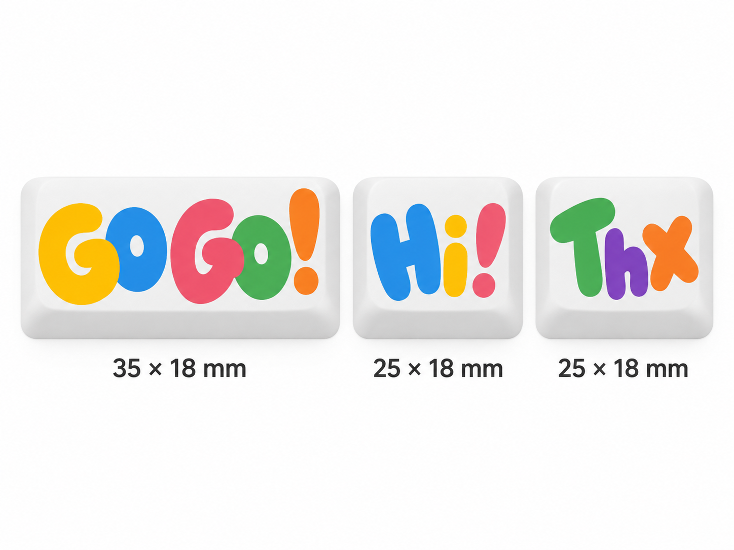
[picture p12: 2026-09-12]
images/key-cap/key-cap3.png

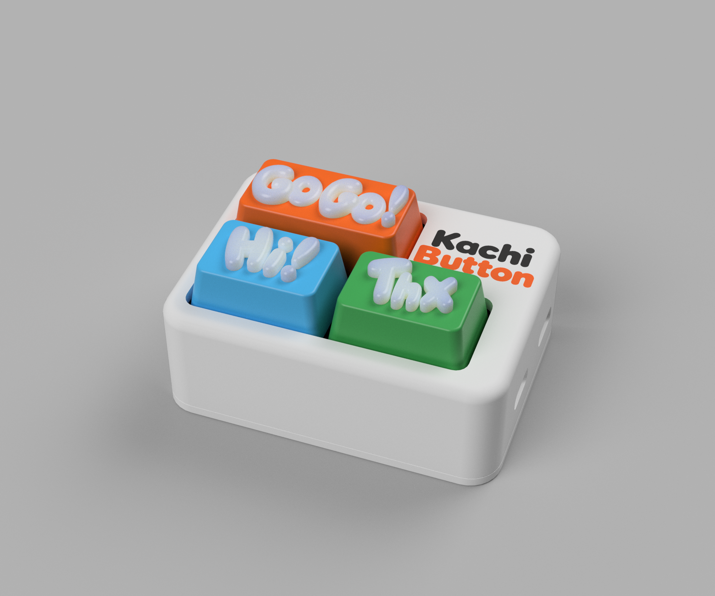
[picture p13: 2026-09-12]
images/enclosure/KachiButton-Enclosure-PLA-v1-3.png

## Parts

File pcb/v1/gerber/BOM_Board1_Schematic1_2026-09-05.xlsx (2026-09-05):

No. | Quantity | Comment | Designator | Footprint | Value | Manufacturer Part | Manufacturer | Supplier Part | Supplier
1 | 2 | 100nF | C1,C2 | C0402 | 100nF | CL05B104KO5NNNC | SAMSUNG(三星) | C1525 | LCSC
2 | 1 | 1uF | C3 | C0402 | 1uF | CL05A105KA5NQNC | SAMSUNG(三星) | C52923 | LCSC
3 | 1 | YLED0603YG | D1 | LED0603-FD |  | YLED0603YG | YONGYUTAI(永裕泰) | C19171392 | LCSC
4 | 1 | TYPE-C16PIN | J1 | USB-C-SMD_TYPE-C16PIN |  | TYPE-C16PIN | SHOU HAN(首韩) | C393939 | LCSC
5 | 2 | 5.1kΩ | R1,R2 | R0402 | 5.1kΩ | 0402WGF5101TCE | UNI-ROYAL(厚声) | C25905 | LCSC
6 | 1 | 1kΩ | R3 | R0402 | 1kΩ | 0402WGF1001TCE | UNI-ROYAL(厚声) | C11702 | LCSC
7 | 3 | CPG151101D13 | SW1,SW2,SW3 | KEY-TH_CPG151101D21X |  | CPG151101D13 | HanElectricity(瀚源) | C49234235 | LCSC
8 | 1 | CH552E | U1 | MSOP-10_L3.0-W3.0-P0.50-LS5.0-BL |  | CH552E | WCH(南京沁恒) | C967938 | LCSC
9 | 1 | SRV05-4 | U2 | SOT-23-6_L2.9-W1.6-P0.95-LS2.8-BL |  | SRV05-4 | TECH PUBLIC(台舟) | C558418 | LCSC

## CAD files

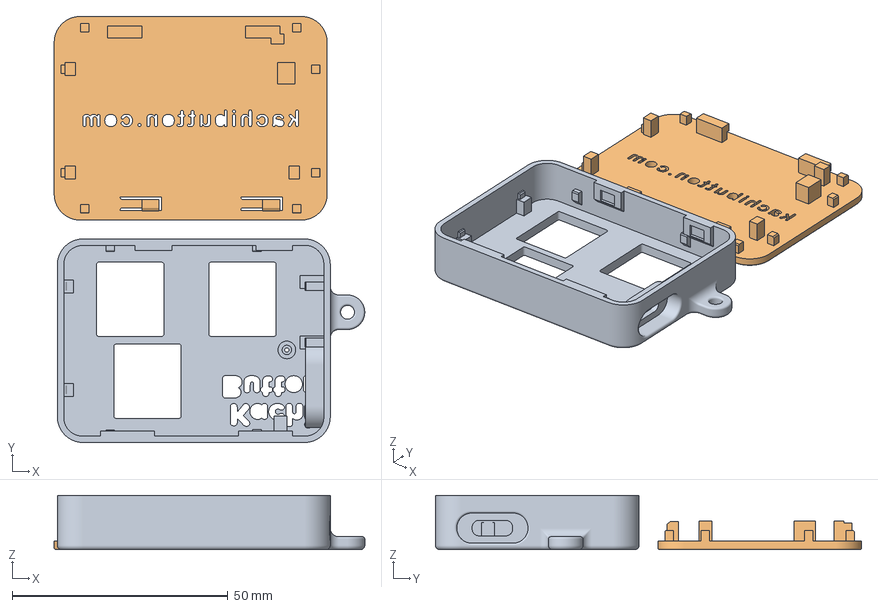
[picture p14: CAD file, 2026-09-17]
3d-models/enclosure-pla-v1/KachiButton-Enclosure-PLA-v1.3mf
72.0 x 98.8 x 12.6 mm
KachiButton-Enclosure-PLA-v1-Top.stl
KachiButton-Enclosure-PLA-v1-Bottom.stl

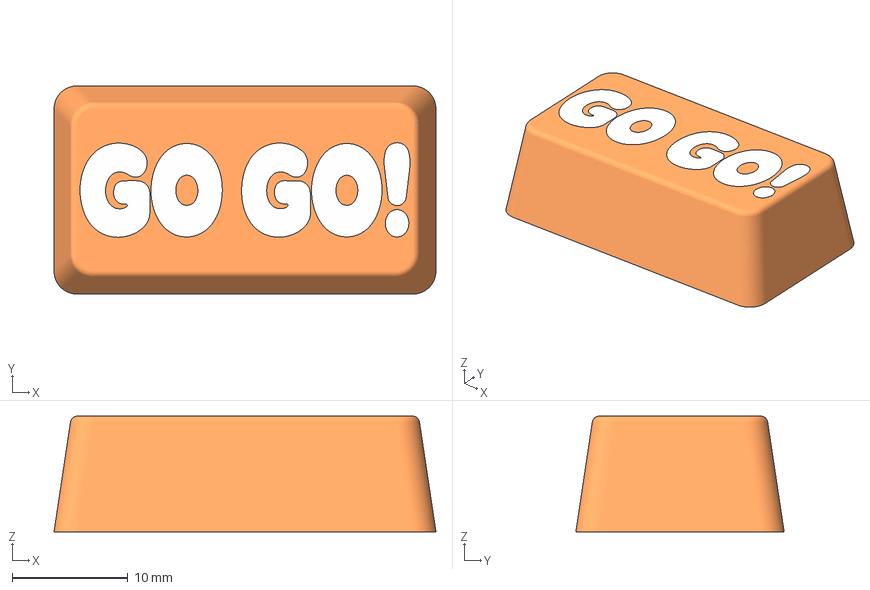
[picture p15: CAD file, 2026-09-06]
3d-models/key-cap/flat/KachiButton-Keycap-Go-go-33x18x10.3mf
33.0 x 18.0 x 10.0 mm
Orange keycap shell
SVG white legend 1
SVG white legend 2
SVG white legend 3
SVG white legend 4
SVG white legend 5
SVG white legend 6

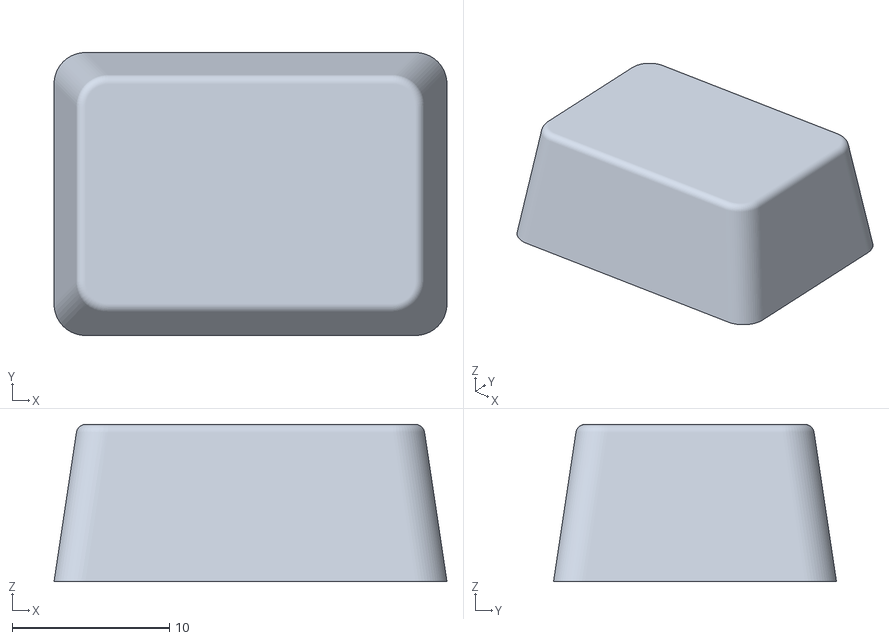
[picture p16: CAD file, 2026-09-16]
3d-models/key-cap/KachiButton-Keycap-Sample-Blank-25x18x10.stl
25.0 x 18.0 x 10.0

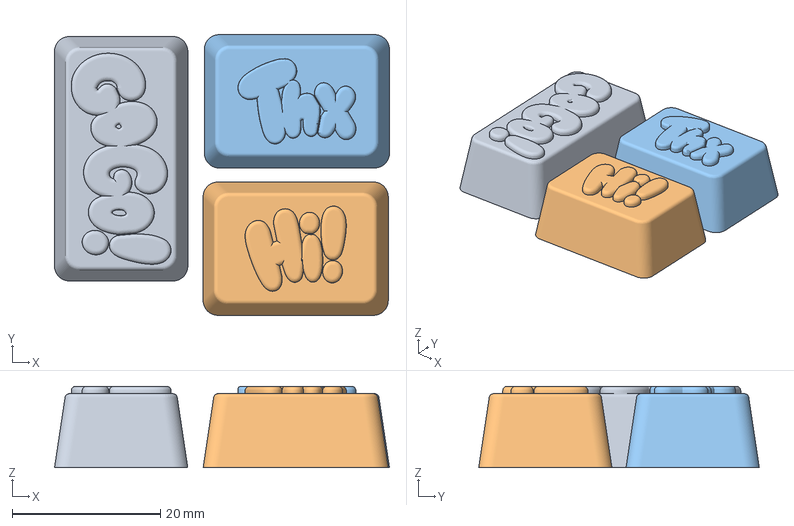
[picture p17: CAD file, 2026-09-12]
3d-models/key-cap/pukkuri/KachiButton-Keycaps-Pukkuri.3mf
45.2 x 37.9 x 11.0 mm
KachiButton-Keycap-Go-go-Raised-33x18x11
KachiButton-Keycap-Hi-Raised-25x18x11
KachiButton-Keycap-Thx-Raised-25x18x11

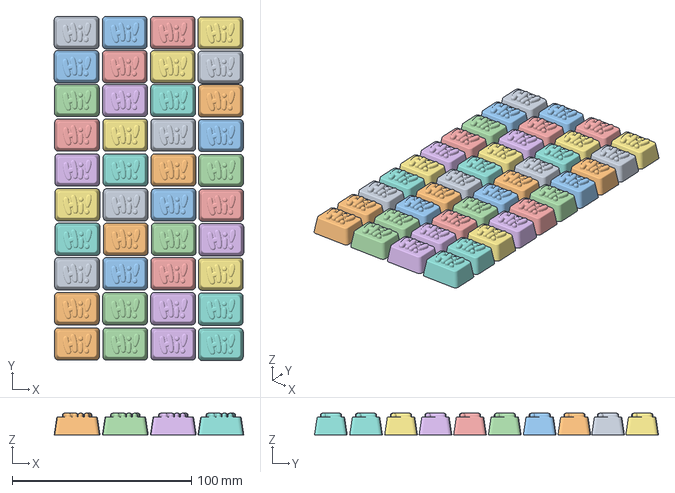
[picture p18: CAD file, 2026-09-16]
3d-models/key-cap/pukkuri2/KachiButton-Keycap-40sets-Hi-Pukkuri2.3mf
105.8 x 191.9 x 12.0 mm
KachiButton-Keycap-Hi-Pukkuri2-25x18x13 x 40

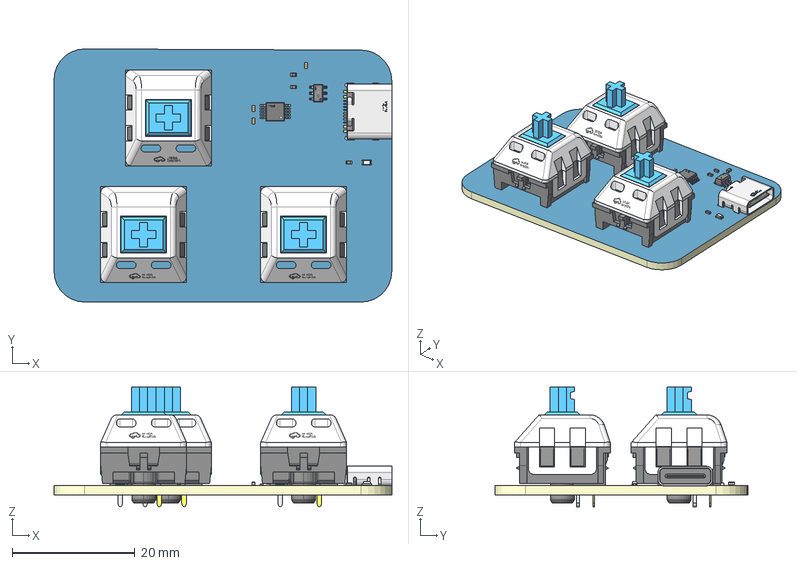
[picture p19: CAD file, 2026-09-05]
pcb/v1/board-3d-data/3D_PCB1_2026-09-05.step
55.0 x 41.2 x 19.4 mm
Board~xmcV
TopCopper~xmcV
BottomCopper~xmcV
TopFpcStiffener~xmcV
BottomFpcStiffener~xmcV
LED0603-FD~LED0603_Inf~xmcV
R0402~R0402_L1.0-W0.5-H0.4~xmcV x 3
MSOP-10_L3.0-W3.0-P0.50-LS5.0-BL~MSOP-10_ L3.0-W3.0-H1.1-LS5.0-P0.50~xmcV
USB-C-SMD_TYPE-C16PIN~USB-C-SMD_TYPE-C16PIN~xmcV
KEY-TH_CPG151101D21X~KEY-TH_L15.6-W14.0-H15.3~xmcV x 3
SOT-23-6_L2.9-W1.6-P0.95-LS2.8-BL~SOT-23-6_ L2.9-W1.6-H1.5-LS2.8-P0.95~xmcV
C0402~C0402_L1.0-W0.5-H0.5~xmcV x 3

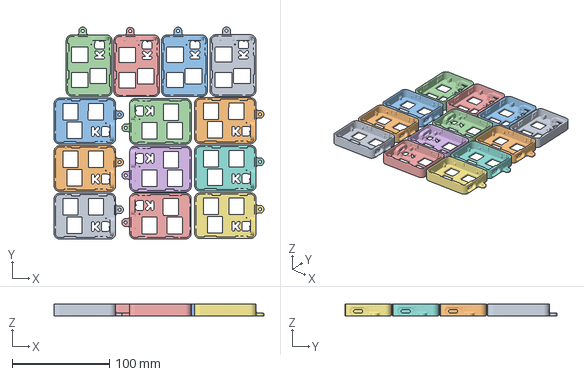
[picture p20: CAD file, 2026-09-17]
3d-models/enclosure-pla-v1/KachiButton-Enclosure-PLA-v1-Top-12sets.3mf
215.5 x 217.9 x 12.6 mm
KachiButton-Enclosure-PLA-v1-Top.stl x 13

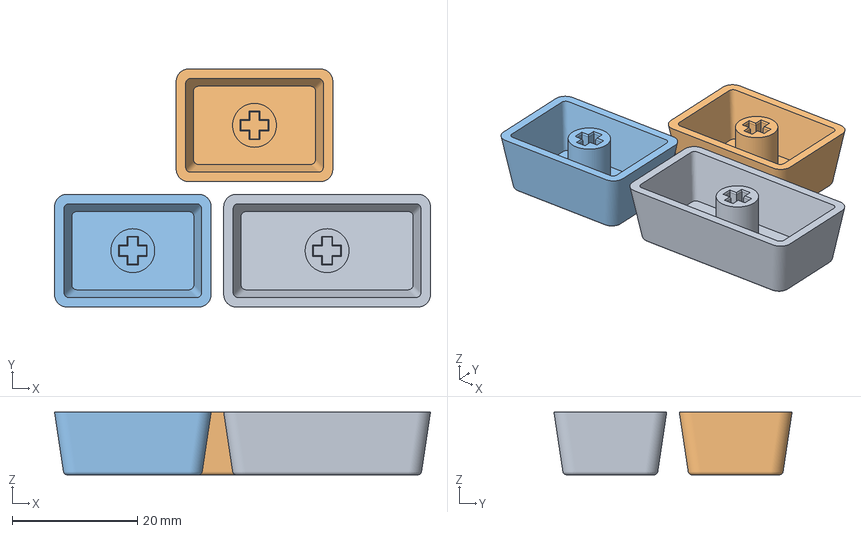
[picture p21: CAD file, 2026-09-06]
3d-models/key-cap/flat/KachiButton-Keycaps.3mf
60.0 x 38.0 x 10.0 mm
KachiButton-Keycap-Go-go-33x18x10
KachiButton-Keycap-Hi-25x18x10
KachiButton-Keycap-Thx-25x18x10

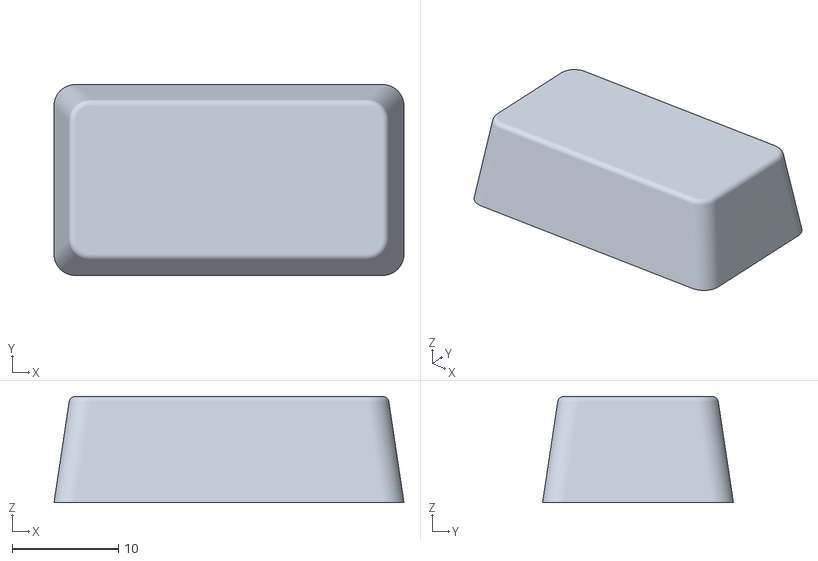
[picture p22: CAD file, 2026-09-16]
3d-models/key-cap/KachiButton-Keycap-Sample-Blank-33x18x10.stl
33.0 x 18.0 x 10.0

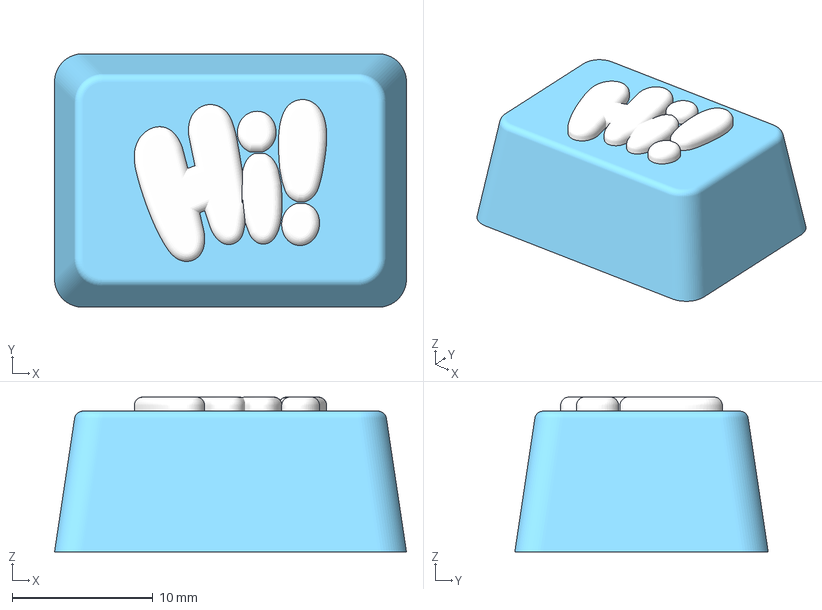
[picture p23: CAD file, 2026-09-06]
3d-models/key-cap/pukkuri/KachiButton-Keycap-Hi-Raised-25x18x11.3mf
25.0 x 18.0 x 11.0 mm
Light blue keycap shell
Raised white legend 1
Raised white legend 2
Raised white legend 3
Raised white legend 4

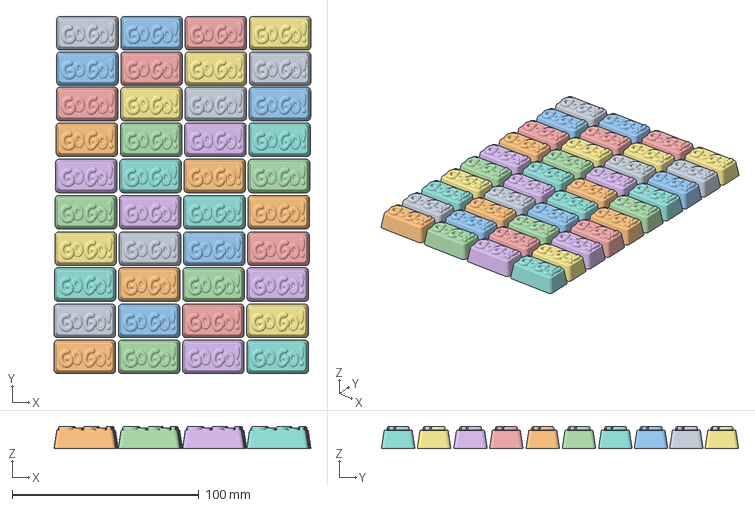
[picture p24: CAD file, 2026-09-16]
3d-models/key-cap/pukkuri2/KachiButton-Keycap-40sets-Go-Go-Pukkuri2.3mf
137.7 x 191.4 x 12.0 mm
KachiButton-Keycap-GoGo-Pukkuri2-33x18x13 x 40

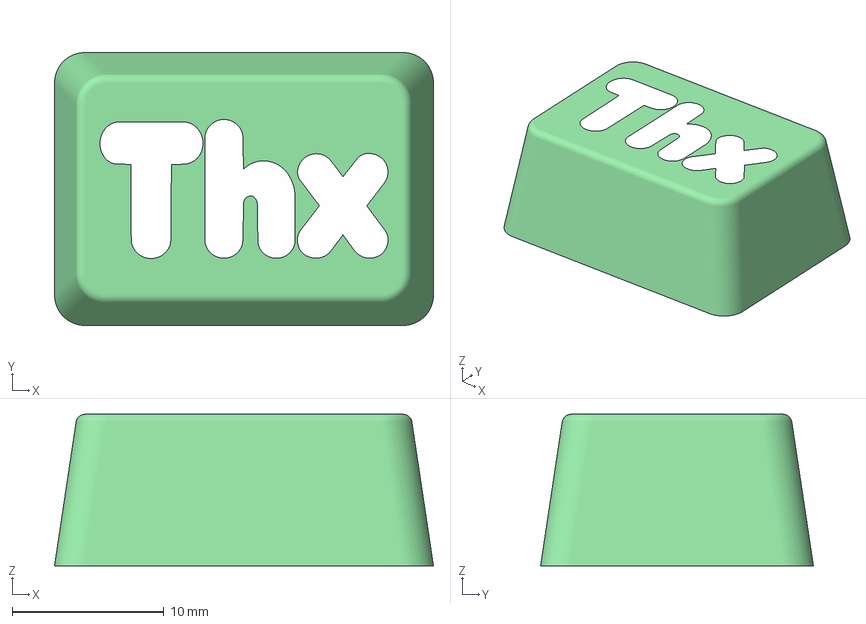
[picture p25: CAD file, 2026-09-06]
3d-models/key-cap/flat/KachiButton-Keycap-Thx-25x18x10.3mf
25.0 x 18.0 x 10.0 mm
Green keycap shell
SVG white legend 1
SVG white legend 2
SVG white legend 3

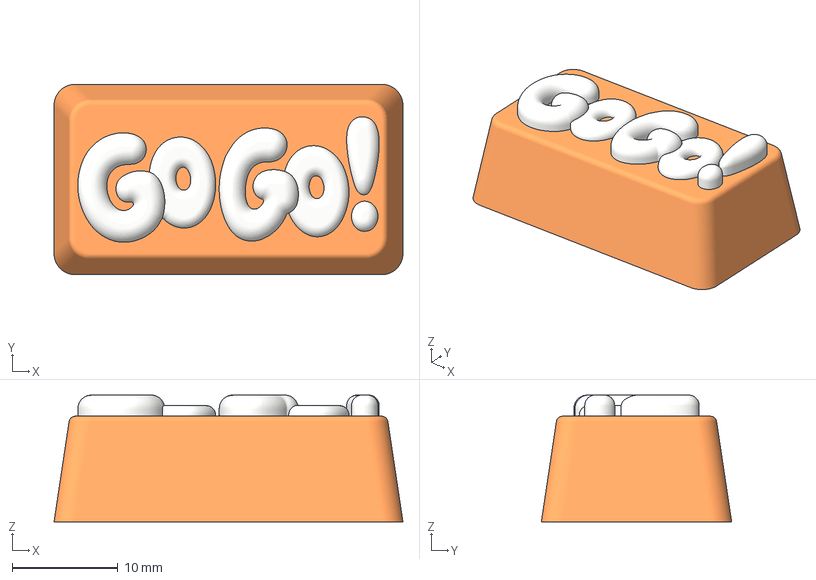
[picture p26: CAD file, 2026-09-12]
3d-models/key-cap/pukkuri2/KachiButton-Keycap-GoGo-Pukkuri2-33x18x13.3mf
33.0 x 18.0 x 12.0 mm
Orange keycap shell
Pukkuri2 Fill-17 #F77D27 H3
Pukkuri2 Fill-20 #F77D27 H3
Pukkuri2 Fill-22 #F77D27 H3
Pukkuri2 Fill-25 #F77D27 H3
Pukkuri2 Fill-27 #2690E7 H2
Pukkuri2 Fill-31 #2690E7 H2

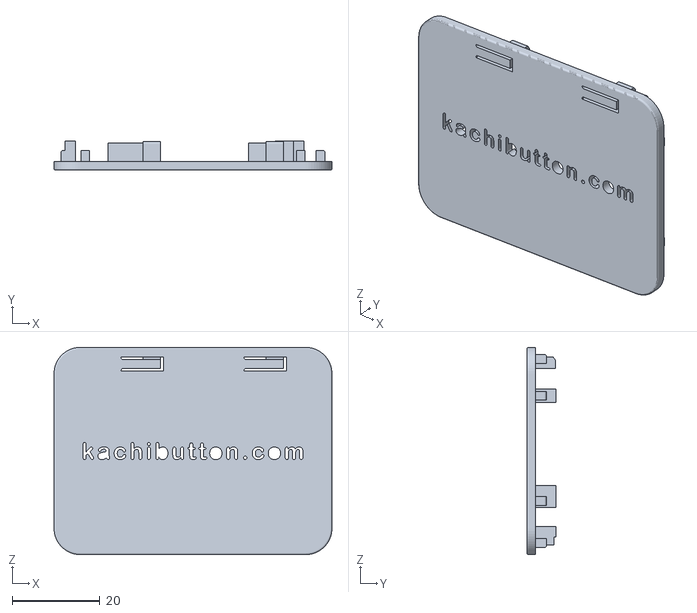
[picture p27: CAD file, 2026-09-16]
3d-models/enclosure-pla-v1/KachiButton-Enclosure-PLA-v1-Bottom.stl
63.3 x 6.70 x 47.2

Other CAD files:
3d-models/enclosure-pla-v1/KachiButton-Enclosure-PLA-v1-Bottom-12sets.3mf
3d-models/key-cap/pukkuri/KachiButton-Keycap-Thx-Raised-25x18x11.3mf
3d-models/key-cap/flat/KachiButton-Keycap-Hi-25x18x10.3mf
3d-models/key-cap/pukkuri/KachiButton-Keycap-Go-go-Raised-33x18x11.3mf
3d-models/enclosure-pla-v1/KachiButton-Enclosure-PLA-v1-Top.stl
3d-models/key-cap/pukkuri2/KachiButton-Keycap-40sets-Thx-Pukkuri2.3mf
3d-models/key-cap/pukkuri2/KachiButton-Keycap-Hi-Pukkuri2-25x18x13.3mf
3d-models/key-cap/pukkuri2/KachiButton-Keycap-Thx-Pukkuri2-25x18x13.3mf

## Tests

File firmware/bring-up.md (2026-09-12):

# Bring-up record — September 12, 2026

Target: manufactured Kachi Button PCB v1, connected by USB-C to macOS.

Sections are historical snapshots for individual builds. Later sections supersede
earlier pending checks when explicitly verified. The [current feature inventory](../docs/firmware-features.md) summarizes current evidence; the latest flashed build is the normally-off HID LED revision.

- Initial enumeration: WCH ISP `4348:55e0`.
- Read-only identification: CH552 (`0x5211`), bootloader 2.50.
- Native scanner/report tests: passed.
- CH552 compilation: passed, 24 MHz internal clock.
- Flash: 5,283 / 14,336 bytes; application XRAM: 134 / 876 bytes.
- USB XRAM reservation: 148 bytes; internal stack region: 210 bytes available
  according to the linker (not a measured stack high-water mark).
- `wchisp flash`: programmed and verified successfully (`Verify OK`).
- HEX SHA-256: `45192d3b7dbb4032d6425727c106f8bc6fcfbf0af0fda734f75891331da0c44d`.
- Post-reset USB descriptor: `Kachi Button`, manufacturer `CreatorKanata`,
  VID:PID `1209:c55d`.
- HID driver registration: confirmed via `hidutil list`, USB usage page 1,
  usage 6 (keyboard), AppleUserUSBHostHIDDevice.
- macOS Keyboard Setup Assistant appeared for CreatorKanata; dismiss it with
  Quit because this three-key device has no full keyboard layout to identify.
- Physical key input: user confirmed correct operation by typing `KNAKNA`
  with the device, then explicitly confirming successful input. Top = K,
  lower left = N, lower right = A; repeated press cycles worked.

Not yet tested: recovery entry via D+ pull-up, other operating systems,
power consumption/suspend current, ESD, and physical switch bounce measurements.

## Fixed-text revision

Requested mappings: ID 0 = `Go Go!`, ID 1 = `Hi!`, ID 2 = `Thx`.
Each press sends exactly the text without Enter or a trailing separator.

- Native key scanner and text report sequence tests: passed.
- Build: 5,652 / 14,336 flash bytes; 137 / 876 application XRAM bytes.
- HEX SHA-256: `7ceda7eee9ffd166e1b8441782e257fdebf88fc0687c93b99072eba7705f4778`.
- Programming: pending hardware entry into WCH USB ISP mode.
- Physical text input: not yet verified. Earlier KNA results apply to the old build.

## Startup button ISP revision (2-second hold)

- Hold all three keys from power-up continuously for 2 seconds to enter USB ISP.
- LED blinks while holding; turns off before handing control to the bootloader.
- Any observed release cancels; normal-use presses cannot rearm the gesture.
- Text is suppressed during the gesture. Fixed texts remain Go Go! / Hi! / Thx.
- Native scanner, text sequencer, and boot gesture tests: passed.
- CH552 build: 6,014 / 14,336 flash bytes; 146 / 876 application XRAM bytes.
- HEX SHA-256: `06889d98cf661207ba4259854f3e2810d333aad8143e06df87fb17507affc346`.
- Flashed to CH552 UID BE-A2-CA-BE on September 12, 2026; `wchisp` returned
  `Verify OK`. After reset, macOS registered Kachi Button as a USB HID keyboard.
- User confirmed correct text input. User observed hold blinking, then off, then
  steady on after attempting ISP entry. A later USB inspection found normal HID;
  the transition into native ISP was not captured.

## Persistent write-wait revision

- Two-second startup gesture latches write-wait; release cannot cancel it.
- Slow hold blinking: 250 ms half-period; fast confirmed waiting: 75 ms half-period.
- No timeout in application waiting; native ISP begins only on uploader command.
- Existing Go Go! / Hi! / Thx mapping preserved.
- Four native C test programs and three Python uploader tests passed, including
  simulated one-hour waiting, timer wrap, and malformed/unarmed command refusal.
- CH552 build: 6,432 / 14,336 flash bytes; 153 / 876 application XRAM bytes.
- HEX SHA-256: `4d3b7866aa18793b688b0b8b99e48a0852dd5e14663c997cf52f2cf1358a8408`.
- macOS libusb opened the existing keyboard without detaching its HID driver;
  the old firmware correctly stalled the unsupported status request.
- Installed on CH552 UID BE-A2-CA-BE at 05:44:25 UTC, September 12, 2026;
  wchisp reported `Verify OK`. The previous two-second gesture successfully
  exposed native ISP for this installation.
- macOS enumerated the new firmware as Kachi Button HID. The new EP0 status
  command returned `WRITE_WAIT (no timeout)` after reset, and again more than
  80 seconds later, confirming wait persistence beyond the 16-bit timer wrap.
- Physical fast-blink appearance and the new uploader-to-ISP command followed
  by flashing remain unverified. No second flash was performed for this check.

## Configurable macros, ms intervals, and remote ISP revision

- Per-key printable ASCII text (0–32 characters), repetitions (1–99), and
  repeat interval (0–60,000 ms). Empty text disables the key.
- Settings can be read/edited in normal mode and explicitly saved to DataFlash.
- Protocol v2 permits host-initiated ISP from normal or write-wait mode.
- Seven native C suites and five Python tests passed, including actual EP0
  adapter tests, timer wrap, settings snapshots, and all partial EEPROM writes.
- CH552 build: 9,247 / 14,336 flash bytes; 382 / 876 application XRAM bytes.
- HEX SHA-256: `9382f03136e373130f44ca30a1575828af89f9475c3d498d21f8fbe302dac127`.
- Installed on CH552 UID BE-A2-CA-BE at 06:36:36 UTC, September 12, 2026;
  wchisp returned `Verify OK`. Status returned protocol v2, normal mode.
- Normal-mode USB configuration read/edit/read-back and EEPROM save succeeded.
  A temporary top-key configuration used the original text, repeat 3, and 250 ms.
- Without any button gesture, the host requested ISP and reflashed the same HEX;
  `Verify OK` at 06:38:01 UTC. The saved test configuration loaded after reset.
- Restored all three original texts, repeat 1, interval 0 ms; saved and read back.
- USB detach exposed a libusb 1.0.29 macOS exit/hotplug deadlock before the first
  upload began. Process sampling localized it to libusb_exit/darwin_exit waiting
  on a detached-device event. Built official libusb 1.0.30 locally, then both
  uploads completed. The host tool now rejects macOS libusb older than 1.0.30.
- Seven C suites and six Python tests pass, including the new dependency guard.
- Physical repeated key output and host-observed ms timing remain unmeasured.
  EEPROM retention across application reset/reflash is verified; unplug/replug
  retention and deliberately interrupted saves have not been physically tested.

## Physical-key LED feedback revision

- Each debounced physical press causes one 10 ms off pulse of the normally lit
  LED, including presses discarded during busy macros. No hold/repeat pulses.
- Startup/write-wait patterns and suspend handling take priority.
- Eight native C suites and six Python tests passed, including pulse boundaries,
  wrap, reset, busy-time press edges, and no timer-wrap retrigger.
- Build: 9,425 / 14,336 flash bytes; 389 / 876 application XRAM bytes.
- HEX SHA-256: `7fca7951f728ed177832d96a7353cc2c476be5078eec526cd1784816ed6a148e`.
- Programmed CH552 BE-A2-CA-BE via normal-mode remote ISP at 07:09:41 UTC,
  September 12, 2026. `Verify OK`; configuration reads succeeded after reset.
- Saved Go Go! / Hi! / Thx, repeat 1, interval 0 ms remained intact.
- Physical LED waveform duration has not been measured; 10 ms is the software
  timer target, subject to main-loop scheduling and interrupt latency.

## 30 ms LED feedback revision

- Changed the physical-key off pulse from 10 ms to 30 ms; USB polling remains 10 ms.
- Eight C suites and six Python tests passed. Build: 9,425 flash bytes, 389 XRAM bytes.
- HEX SHA-256: `1060a58a6579e76caaa09e9d5efdf2fdc0ee0b9bdebf015477dcf6402ec81e2f`.
- Flashed CH552 BE-A2-CA-BE through host-only ISP at 08:19:01 UTC on September 12,
  2026; `Verify OK`. Post-reset configuration reads succeeded with the saved
  Go Go! / Hi! / Thx, repeat 1, interval 0 ms intact.
- LED duration is a software timer target; physical waveform remains unmeasured.

## Normally-off HID LED revision

- Active HID entry lights the LED for 2 seconds, followed by idle off.
- Each subsequent debounced physical press lights it for 30 ms, then off.
- Entry indication takes priority over press feedback without blocking typing;
  USB resume/reconfiguration restarts it. Boot hold/write-wait patterns retained.
- Eight C suites and six Python tests passed, including both duration boundaries,
  startup priority, lifecycle reset, and timer wrap.
- Build: 9,519 flash bytes / 14,336; 389 application XRAM bytes / 876.
- HEX SHA-256: `e7699e02404883d993054a9ebe61ae6ce0badbfe94b544e6bec63ef76e48584c`.
- Flashed CH552 BE-A2-CA-BE via normal-mode host upload at 08:32:15 UTC,
  September 12, 2026; `Verify OK`. Post-reset configuration reads succeeded;
  original text/count/interval settings remained intact.
- Physical LED polarity/appearance and durations have not been instrumented.

## Save-completion LED revision

- A verified settings save in normal HID mode lights the LED for 1 second.
  Temporary apply and failed saves do not trigger success feedback.
- Eight C suites and six Python tests passed; timing tests include wrap, failure,
  repeated saves, key/entry priority, and lifecycle reset.
- Build: 9,609 / 14,336 flash bytes; 394 / 876 application XRAM bytes.
- HEX SHA-256: `7c758311f587bace7bd079b28a5f24cb3a178d07c1341a0a2a14b589611ddb01`.
- Flashed CH552 BE-A2-CA-BE through normal-mode remote ISP; `Verify OK` at
  18:42:12 UTC September 12, 2026 (September 13 JST).
- Post-reset unchanged save completed with result 0, saving false, unsaved false.
  Go Go! / Hi! / Thx, repeat 1, interval 0 ms remained intact.
- Browser save interaction and physical LED duration were not observed in this
  test; the host tool exercised the same firmware save command.

## Factory chip ID revision

- Added optional read-only request 0x66: KI, format 1, 40-bit ID (MSB first).
- Eight native C suites, six Python tests, and eight browser protocol tests passed.
- Build: 9,753 / 14,336 flash bytes; 397 / 876 application XRAM bytes.
- HEX SHA-256: `41e0231dd8898f3ff388bb77b562c7fec474094cf40df290d899522911c38e1e`.
- Flashed CH552 BE-A2-CA-BE; Verify OK at 18:47:30 UTC September 12, 2026
  (September 13 JST). Normal-mode reads returned factory ID `79-BE-CA-A2-BE`
  twice. The lower four bytes, reversed, match the ISP UID BE-A2-CA-BE.
- Go Go! / Hi! / Thx, count 1, interval 0 remained saved after reset.
- Host USB verified the same new request used by Read device; actual browser
  rendering/interaction remains unverified due to the earlier automation restriction.

## USB manufacturer revision

- New USB manufacturer: `HAPT Lab, LLC`; product remains `Kachi Button`.
- Host tools and HTML accept the former `CreatorKanata` identity for upgrades.
  Other manufacturers remain rejected.
- Eight C suites, seven Python tests, and nine browser protocol tests passed.
- Build: 9,753 / 14,336 flash bytes; 397 / 876 application XRAM bytes.
- HEX SHA-256: `6ea7d1b452e13cd46a855ca137f394a4a315296f22dea3562baf91eca48ac550`.
- Flashed with Verify OK at 19:04:09 UTC September 12, 2026 (September 13 JST).
- Read the actual USB manufacturer descriptor after reset: `HAPT Lab, LLC`.
  Factory ID remains `79-BE-CA-A2-BE`. Saved Go Go!!! / Hi! / Thx, count 1,
  interval 0 ms remained intact, with no unsaved settings.

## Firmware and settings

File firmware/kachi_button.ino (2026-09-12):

/* Kachi Button PCB v1: Go Go! / Hi! / Thx, one text macro per press. */
#include "src/keys.h"
#include "src/text.h"
#include "src/transport.h"
#include "src/boot_gesture.h"
#include "src/settings.h"
#include "src/storage.h"
#include "src/key_led.h"

static const uint8_t pins[KEY_COUNT] = KEY_PINS;
static uint8_t report[8];
static uint8_t epoch;

static uint8_t read_keys(void) {
    uint8_t i, pressed = 0;
    for (i = 0; i < KEY_COUNT; ++i)
        if (!digitalRead(pins[i]))
            pressed |= 1 << i;
    return pressed;
}

void setup(void) {
    uint8_t i;
    digitalWrite(LED_PIN, HIGH);
    pinMode(LED_PIN, OUTPUT);
    for (i = 0; i < KEY_COUNT; ++i)
        pinMode(pins[i], INPUT_PULLUP);
    keys_reset(read_keys(), (uint16_t)millis());
    boot_gesture_init(read_keys(), (uint16_t)millis());
    settings_init();
    text_reset();
    key_led_reset();
    USBInit();
}

void loop(void) {
    uint16_t now = (uint16_t)millis();
    uint8_t pressed = read_keys();
    uint8_t action;
    uint8_t boot = boot_gesture_poll(pressed, now);
    /* Save runs outside the USB ISR; EEPROM writes mask interrupts per byte. */
    if (settings_saving) {
        uint8_t ok = storage_save();
        /* EEPROM work takes time: start feedback at completion, not loop entry. */
        now = (uint16_t)millis();
        key_led_save_finished(ok, now);
        settings_finish_save(ok);
    }
    if (kachi_boot_requested) {
        digitalWrite(LED_PIN, HIGH);
        enter_bootloader();
    }
    /* Latch waiting before USB lifecycle handling: bus reset cannot cancel it. */
    if (boot != BOOT_NORMAL) {
        keys_reset(pressed, now);
        text_reset();
        key_led_reset();
        kachi_waiting = boot == BOOT_WAIT;
        digitalWrite(LED_PIN, (now / (kachi_waiting ?
            BOOT_WAIT_LED_HALF_PERIOD_MS : BOOT_LED_HALF_PERIOD_MS)) & 1);
        return;
    }
    if (!UsbConfig || usbSuspended || epoch != kachi_usb_epoch) {
        epoch = kachi_usb_epoch;
        keys_reset(pressed, now);
        text_reset();
        key_led_reset();
        digitalWrite(LED_PIN, HIGH);
        return;
    }
    action = keys_scan(pressed, now, !text_busy() && hid_ready());
    digitalWrite(LED_PIN, key_led_on(keys_pressed_edges, now) ? LOW : HIGH);
    if (action) {
        /* Snapshot a whole macro atomically against USB configuration updates. */
        uint8_t saved = IE_USB;
        IE_USB = 0;
        text_start(action);
        IE_USB = saved;
    }
    text_tick(now);
    if (hid_ready() && text_peek(keyboardLedStatus & HID_CAPS_LOCK_LED, report))
        if (hid_send(report, epoch))
            text_accepted(now);
}

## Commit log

2026-09-05 Add PCB v1 manufacturing files and project documentation
    [3D_PCB1_2026-09-05.step, BOM_Board1_Schematic1_2026-09-05.xlsx, PickAndPlace_PCB1_2026-09-05.xlsx]
2026-09-05 Add PCB v1 board previews to READMEs
2026-09-05 Organize PCB v1 exports and update release links
    [3D_PCB1_2026-09-05.step, BOM_Board1_Schematic1_2026-09-05.xlsx, PickAndPlace_PCB1_2026-09-05.xlsx]
2026-09-05 Document product, PCB, firmware, and enclosure specifications
2026-09-05 Organize specifications and document PCB component sourcing
2026-09-05 Record two blank keycap print samples
2026-09-06 Add keycap 3D models and updated artwork
    [KachiButton-Keycap-Go-go-33x18x10.3mf, KachiButton-Keycap-Hi-25x18x10.3mf, KachiButton-Keycap-Thx-25x18x10.3mf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]
2026-09-06 Add compact PLA enclosure with reinforced below-board snap fits
    [KachiButton-Enclosure-Bottom.3mf, KachiButton-Enclosure-Bottom.step, KachiButton-Enclosure-Top.3mf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]
2026-09-06 Update keycap variants, enclosure models, and product images
    [KachiButton-Enclosure-Bottom.3mf, KachiButton-Enclosure-Bottom.step, KachiButton-Enclosure-Top.3mf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]
2026-09-12 Update HID LED startup indication and key feedback
2026-09-12 Update enclosure, keycap models, and artwork
    [KachiButton-Enclosure-Bottom.3mf, KachiButton-Enclosure-Bottom.step, KachiButton-Enclosure-PLA-v1.3mf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]
2026-09-16 Update enclosure and keycap print exports
    [KachiButton-Enclosure-PLA-v1-Bottom.stl, KachiButton-Enclosure-PLA-v1-Top.stl, KachiButton-Enclosure-PLA-v1.3mf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]
2026-09-16 Use PLA v2 enclosure rendering as the README hero image
2026-09-17 Update enclosure STL and 3MF print files
    [KachiButton-Enclosure-PLA-v1-Bottom-12sets.3mf, KachiButton-Enclosure-PLA-v1-Top-12sets.3mf, KachiButton-Enclosure-PLA-v1.3mf]
